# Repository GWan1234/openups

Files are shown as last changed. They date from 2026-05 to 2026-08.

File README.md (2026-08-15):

# OpenUPS-ESP32S3

基于 ESP32-S3 的智能锂电池 UPS 控制系统，使用 BQ24780S/BQ24800 充电管理芯片与 BQ76920 电池监控芯片实现BMS管理，支持 3-5 串锂离子/磷酸铁锂电池，12-19V 宽电压输入。

以下英文为机翻：

An intelligent lithium battery UPS control system based on ESP32-S3, using BQ24780S/BQ24800 charger IC and BQ76920 battery monitor IC for BMS management, supporting 3-5 cell Li-ion/LiFePO4 batteries with 12-19V wide voltage input.

> **为什么不用铅酸 UPS？** 铅酸 UPS 待机功耗 10W+，体积笨重。本项目面向小功率主机、NAS、软路由、网络设备等场景，锂电池方案更小巧、更省电、更安静。
> **Why not lead-acid UPS?** Lead-acid UPS has 10W+ standby power consumption and bulky size. This project targets low-power hosts, NAS, soft routers, and network devices — lithium battery solutions are smaller, more energy-efficient, and quieter.

> **会不会炸飞老铁？** 做这个东西的初衷就是思考——为什么锂电池不安全？一个是电池管理问题，一个是心理暗示。电池管理方面，放弃粗暴的浮充方式，可设定充电起止范围，让电池在最佳区间保存，同时可精准限定充电电压、电流，还可以限定充电窗口时间，再就是电池管理芯片也要用好的，很多芯片的误差范围很大。心理方面，那就把所有信息都透明显示、可监控，这不还可以用 HA 或者米家联动嘛。其实家里锂电池设备好多——笔记本电脑、各种吸尘器、扫地机器人、洗地机、牙刷、剃须刀……如果谈不安全，都不安全。而且本项目的设计就是让电池一直处于安全的中间电量阶段范围（40%～80%），UPS 充电次数很少，一年也就几次。
> **Will it explode?** The original motivation was to think — why are lithium batteries unsafe? Two factors: battery management and psychological perception. On management: we abandon crude float charging, allowing configurable charge start/stop ranges to keep batteries in optimal zones, with precise voltage/current limits and time windows. Quality battery management chips matter — many have large error margins. On perception: display all information transparently and make it monitorable — you can even integrate with Home Assistant or Xiaomi Home. Actually, many household devices use lithium batteries — laptops, vacuums, robot vacuums, floor washers, electric toothbrushes, razors... If we're talking about safety risks, they all have them. Moreover, this project keeps batteries in the safe middle range (40%~80%), with very few charge cycles per year — just a few times.

> **为什么不用磷酸铁锂？** 磷酸铁锂长期处于浅充浅放状态，库仑计会有巨大积累误差，也许某天真正停电就失速了。综合来说，还是三元锂更符合预期。
>
> **Why not LiFePO4?** LiFePO4 in long-term shallow charge/discharge cycles causes huge accumulated errors in the coulomb counter — when a real power outage occurs, it may fail unexpectedly. Overall, ternary lithium (NCM/NCA) better meets expectations.
>
> ----------------------------------------------------------
>
> **最新代码新增了磷酸铁锂的支持，可我没有磷酸铁锂电池，所以并没有测试，请自行评估。**
>
> **The latest commit adds support for LFP (LiFePO₄) batteries. However, since I don't have an LFP battery on hand, this feature has not been tested. Use at your own risk.**

> **怎么接入米家？** 把米家温湿度计上的传感器拆掉，通过 I2C 连接到主板。系统模拟 I2C Slave（SHTC3 协议），将电池温度和 SOC（用湿度字段替代）传送给米家温湿度计，从而接入米家智能家居生态。当然这个功能是可选的——毕竟要拆一只温湿度计来实现。详见 [版本说明 - v2 特性变化](#v2-特性变化)。
> **How to integrate with Xiaomi Home?** Remove the sensor from a Xiaomi temperature/humidity monitor and connect it to the mainboard via I2C. The system simulates an I2C Slave (SHTC3 protocol), transmitting battery temperature and SOC (using the humidity field) to the Xiaomi monitor, thereby integrating into the Xiaomi smart home ecosystem. This feature is optional — it requires disassembling a monitor. See [Version Notes - v2 Feature Changes](#v2-feature-changes).

> **电池的选择** 其实UPS常年都是空置，很难使用到一次，一年也就充电多次，没有必要用全新的电池，但一定要用可靠的电池。比如说家里各个设备淘汰下来的电池，吸尘器，扫地机器人，洗地机，甚至手电钻等等，都可以梯次利用，作为ups发光发热。不过这些设备电池在使用前，一定要尽量充电到电压一致，靠bq76920那微弱的平衡能力（增加外置大功率平衡是没有必要的），是需要很久很久很久的。
> **Battery selection** UPS units are typically idle, rarely used, and only charge a few times per year — there's no need for brand new batteries, but they must be reliable. For example, retired batteries from household devices (vacuums, robot vacuums, floor washers, even power drills) can be repurposed for UPS use. However, these batteries must be charged to matching voltages before use — relying on the BQ76920's slow balancing capability (external high-power balancing is unnecessary) would take an extremely long time.

## 功能特性
## Features

### 核心功能
### Core Features

- **USB HID UPS** — ESP32-S3 原生 USB 接口，Windows/macOS/Linux 自动识别为标准 UPS 设备，支持低电量安全关机
- **USB HID UPS** — ESP32-S3 native USB interface, automatically recognized as standard UPS device by Windows/macOS/Linux, supports low-battery safe shutdown
- **充放电管理** — BQ24780S/BQ24800 充电控制，支持自适应充电电流、定时充电窗口（5 组周计划）、混合供电模式
- **Charge/Discharge Management** — BQ24780S/BQ24800 charging control with adaptive charge current, scheduled charging windows (5 weekly plans), hybrid power supply mode
- **电池管理** — BQ76920 电池监控，库仑计 SOC 计算、SOH 学习、自动均衡、多重保护（OV/UV/OCD/SCD/OT）
- **Battery Management** — BQ76920 battery monitoring with coulomb counter SOC calculation, SOH learning, auto-balancing, multiple protections (OV/UV/OCD/SCD/OT)
- **Web 仪表盘** — SPA 单页应用，macOS 风格 UI，实时 WebSocket 数据推送（3 秒间隔）
- **Web Dashboard** — SPA single-page application with macOS-style UI, real-time WebSocket data push (3-second interval)
- **OTA 固件更新** — 网页拖拽上传固件，带签名校验，双分区安全升级
- **OTA Firmware Update** — Web-based drag-and-drop firmware upload with signature verification, dual-partition safe upgrade
- **MQTT 集成** — Home Assistant 自动发现，支持 TLS 加密连接
- **MQTT Integration** — Home Assistant auto-discovery with TLS encrypted connection support
- **Prometheus 监控** — `/metrics` 端点，可直接接入 Grafana
- **Prometheus Monitoring** — `/metrics` endpoint, directly compatible with Grafana
- **米家集成** — 借助米家温湿度计，绕道接入米家，实现温度，SOC与米家系统联动
- **Xiaomi Home Integration** — Via Xiaomi temperature/humidity monitor, indirect integration with Xiaomi Home for temperature and SOC linkage
- **WEBHOOK—**新增webhook用于信息推送（测试中，欢迎反馈）
- **WEBHOOK—**New webhook added for message pushing (in testing, feedback is welcome)

### 保护机制
### Protection Mechanisms

| 保护类型 | 说明 |
| Protection Type | Description |
|---|---|
| 过压保护 (OV) | 单体电压超阈值，切断充电 FET |
| Overvoltage Protection (OV) | Cell voltage exceeds threshold, charging FET cut off |
| 欠压保护 (UV) | 单体电压低于阈值，切断放电 FET |
| Undervoltage Protection (UV) | Cell voltage below threshold, discharging FET cut off |
| 过流保护 (OCD) | 放电电流超限 |
| Overcurrent Protection (OCD) | Discharge current exceeds limit |
| 短路保护 (SCD) | 短路快速响应 |
| Short Circuit Protection (SCD) | Fast short-circuit response |
| 过温保护 | 板载 + 环境温度双重检测 |
| Overtemperature Protection | Board + ambient temperature dual detection |
| 充电超时 | 防止异常长时间充电 |
| Charge Timeout | Prevents abnormal prolonged charging |
| 系统状态机 | INIT → NORMAL → WARNING → CRITICAL 四级状态管理 |
| System State Machine | INIT → NORMAL → WARNING → CRITICAL four-level state management |

## 版本说明
## Version Notes

### v1 与 v2 区别
### Differences between v1 and v2

v2 与 v1 最大的区别是从开发板换成了贴片模块，去掉了一个 USB 口，缩小了整体体积。
The biggest difference between v2 and v1 is switching from a development board to a SMT module, removing one USB port, and reducing overall size.

v1 与 v2 都支持 **BQ24780S** 与 **BQ24800**，两者引脚兼容。区别是 BQ24800 支持升压输出——有总比没有好。
Both v1 and v2 support **BQ24780S** and **BQ24800**, which are pin-compatible. The difference is BQ24800 supports boost output — better to have than not.

> v2 用 **4 层板**，6 层板是因为领错了券，纯属浪费，对不起嘉立创。
> v2 uses a **4-layer PCB**; the 6-layer board was due to a coupon mistake — a waste, apologies to JLCPCB.

### v2 特性变化
### v2 Feature Changes

v2 没有使用开发板，因此没有 GPIO48 的 RGB 灯。GPIO47/GPIO48 改为 **I2C Slave** 接口，并加了上拉电阻。设计想法是用 GPIO10 模拟电量信号给米家温湿度计供电来显示电量，温度与湿度（可以替换为比如主板温度）通过 I2C Slave 发送给米家温湿度计，从而接入米家智能家居生态。
v2 doesn't use a development board, so there's no GPIO48 RGB LED. GPIO47/GPIO48 are changed to **I2C Slave** interface with pull-up resistors. The design idea is to use GPIO10 to simulate battery level signal for the Xiaomi monitor to display SOC, while temperature and humidity (replacable with e.g. board temperature) are sent via I2C Slave to the Xiaomi monitor, integrating into the Xiaomi smart home ecosystem.

当然，你也可以不用这个功能。米家温湿度计拆下来的传感器没有用了，可以焊在板子预留的焊盘上（代码还没写，回头加上）。到时候是不是可以不用焊接 CN6 以及环境温度 NTC 电阻，用这个替代？
Of course, you can choose not to use this feature. The sensor removed from the Xiaomi monitor can be soldered to the reserved pads on the board (code not yet written, will be added later). Could this replace soldering CN6 and the ambient temperature NTC resistor?

CN6 位置也可以直接把插件 NTC 电阻焊上去，不用那个插座。
The CN6 position can also directly accept a through-hole NTC resistor soldered in place, without using the socket.

> v2 的外壳还没做，代码持续调试升级中，外壳后续做好了再更新。
> v2 enclosure not yet designed; code is continuously being debugged and updated; enclosure will be added later.

### 首次下载程序
### First-Time Programming

启动时按住 **BOOT** 按键（从上到下第二个按钮），再按第三个按钮 **REBOOT**，即可进入下载模式。之后都可以直接通过网页 OTA 更新。
Hold the **BOOT** button (second button from top) during startup, then press the third button **REBOOT** to enter download mode. After that, updates can be done directly via web OTA.

从上往下，v1版本的按键依次是：**电池的激活按键，网络与配置重置按键**

v2版本的按键依次是：**电池的激活按键，esp32s3的boot引导按键，esp32s3的reset按键，网络与配置的重置按键**

led灯从左往右依次为：**ACpower，充电，放电，wifi指示（红色表示未连接，绿色表示已连接wifi）**

### **焊接提示**
### Soldering Tips

焊接板子时，**LDO 5V→3.3V 先不要焊**，先确认 5V 供电正常后再焊上去，以免一波带走芯片。
When soldering the board, **do not solder the LDO 5V→3.3V first** — verify 5V power is normal before soldering it to avoid damaging the chip.

## 硬件
## Hardware

### 关键参数
### Key Specifications

| 参数 | 值 |
| Parameter | Value |
|---|---|
| 输入电压 | 12-19V DC |
| Input Voltage | 12-19V DC |
| 充电电流 | 最高 8128mA（BQ24780S/BQ24800） |
| Charge Current | Up to 8128mA (BQ24780S/BQ24800) |
| 放电电流 | 最高 20A |
| Discharge Current | Up to 20A |
| 输入电流 | 最高 8064mA |
| Input Current | Up to 8064mA |
| 电池类型 | 3-5 串 Li-ion / LiFePO4 |
| Battery Type | 3-5 cell Li-ion / LiFePO4 |
| 电流采样电阻 | 10mΩ（充电侧）/ 5mΩ（放电侧） |
| Current Sense Resistor | 10mΩ (charge side) / 5mΩ (discharge side) |
| I2C 总线 | GPIO11(SDA) / GPIO12(SCL)，100kHz |
| I2C Bus | GPIO11(SDA) / GPIO12(SCL), 100kHz |

### 输出特性说明
### Output Characteristics

这个 UPS 本质上是**电源直通输出**，不具备变压、稳压功能，但可以在电源输出不足的时候，由电池来一起混合输出。当电源掉电的时候，输出的电压实际上就是电池本身的电压，这一点要注意。当然，现在的光猫、路由器、小主机本质上也是宽电压设备，比如 12V 的设备，9-13V 也没什么问题。
This UPS is essentially a **pass-through power output** without voltage conversion or regulation, but it can hybrid-output with the battery when the power supply is insufficient. When power fails, the output voltage is actually the battery's own voltage — keep this in mind. Of course, modern ONTs, routers, and mini PCs are typically wide-voltage devices; for example, a 12V device works fine at 9-13V.

主控 BQ24780S 是可以直接换成 **BQ24800** 的，两者引脚兼容。BQ24800 支持设定一个目标电压，可以让电池升压输出，从而在电源掉电时维持稳定的输出电压。v1 与 v2 均支持 BQ24800（详见[版本说明](#版本说明)）。
The main charger BQ24780S can be directly replaced with **BQ24800** — they are pin-compatible. BQ24800 supports setting a target voltage, enabling boost output from the battery to maintain stable output voltage during power loss. Both v1 and v2 support BQ24800 (see [Version Notes](#version-notes)).

### ESP32 开发板（v1）
### ESP32 Development Board (v1)

v1 使用 **ESP32-S3 N16R8** 版本的开发板（16MB Flash / 8MB PSRAM）。插入时**注意核对引脚排列和插入方向**，反接可能损坏开发板或主板。
v1 uses the **ESP32-S3 N16R8** development board (16MB Flash / 8MB PSRAM). **Verify pin arrangement and insertion direction** — reverse insertion may damage the board or mainboard.

> v2 使用贴片模块，无需开发板，详见[版本说明](#版本说明)。
> v2 uses an SMT module, no development board needed. See [Version Notes](#version-notes).

### 电池夹选择
### Battery Holder Selection

电池组有条件的**尽量选择直接点焊成组**，接触电阻最小、最可靠。
If possible, **directly spot-weld battery packs** — this provides the lowest contact resistance and highest reliability.

如果使用电池夹，建议如下：
If using battery holders, recommendations如下:

| 类型 | 材质 | 优缺点 |
| Type | Material | Pros/Cons |
|---|---|---|
| 插针电池夹 | 钢片 | 夹持力强，但**过紧**，拆装困难 |
| Pin battery holder | Steel | Strong grip, but **too tight**, difficult to install/remove |
| 贴片电池夹 | 铜材质 | 导电好，但**过松**，接触不可靠 |
| SMT battery holder | Copper | Good conductivity, but **too loose**, unreliable contact |
| **贴片铜弹片 + 螺旋弹簧**（推荐） | 黄铜/紫铜 | 导电好，弹簧提供足够的回弹力，**推荐方案** |
| **SMT copper spring + coil spring** (Recommended) | Brass/Copper | Good conductivity, spring provides sufficient rebound force, **recommended solution** |

推荐方案：[贴片铜弹片](https://item.taobao.com/item.htm?id=833701074625) + 线径 0.8mm × 外径 5mm × 长度 50mm 的螺旋弹簧配合使用。弹片负责导电，弹簧负责提供夹持力。
Recommended: [SMT copper spring](https://item.taobao.com/item.htm?id=833701074625) + coil spring (wire diameter 0.8mm × outer diameter 5mm × length 50mm). The copper spring handles conductivity, the coil spring provides clamping force.

> **不建议使用钢片电池夹**，夹持力过大容易损伤电池外壳；纯铜弹片弹力不足，需要搭配螺旋弹簧。
> **Not recommended: steel battery holders** — excessive clamping force can damage battery casing; pure copper springs lack sufficient elasticity and need coil spring pairing.

### 硬件注意事项
### Hardware Notes

- **电池选择** — 电池最好选择品质一致的，并保证初始电压一致。BQ76920 内置的平衡速度极慢，每天大概 20mV 不到。如果是大容量电池，要考虑在线路上增加外部平衡电路，BQ76920 也是支持的
- **Battery Selection** — Choose batteries with consistent quality and matching initial voltages. The BQ76920's built-in balancing is extremely slow, about 20mV per day. For large-capacity batteries, consider adding external balancing circuits on the lines — BQ76920 supports this
- **R27、R66** — 正常情况下**不需要焊接**，这两个电阻用于选择 NTC 与隔离 I2C 芯片的供电源
- **R27, R66** — Normally **do not need soldering** — these resistors select the power source for NTC and isolated I2C chip
- **I2C 隔离芯片** — PCB 设计使用 ISO1640BDR，也可以更换为 ISO1540DR。虽然 ISO1640 标称支持热拔插而 ISO1540 不支持，但实测 ISO1540DR 同样可以正常工作
- **I2C Isolation Chip** — PCB designed for ISO1640BDR, can also use ISO1540DR. Although ISO1640 nominally supports hot-swap while ISO1540 doesn't, testing shows ISO1540DR works fine
- **SW_activate 按键** — 电池刚接入或 BQ76920 进入运输模式后，需要按下此按键一次激活芯片
- **SW_activate Button** — After battery connection or when BQ76920 enters ship mode, press this button once to activate the chip
- **SW_reset 按键** — 长按数秒进入 WiFi AP 模式（重置网络）；开机时持续按住则重新进入配置模式
- **SW_reset Button** — Hold for several seconds to enter WiFi AP mode (reset network); hold during startup to re-enter configuration mode
- **H6、H7 跳线** — 使用 3S 电池需短接 H6，4S 电池需短接 H7（取决于电池串数），**请务必仔细确认后再上电**
- **H6, H7 Jumpers** — Short H6 for 3S batteries, short H7 for 4S batteries (depends on cell count), **please verify carefully before powering on**
- **LDO 焊接顺序（v2）** — 焊接板子时，LDO 5V→3.3V **先不要焊**，先确认 5V 供电正常后再焊上去，以免损坏芯片
- **LDO Soldering Order (v2)** — When soldering, **do not solder LDO 5V→3.3V first** — verify 5V power is normal before soldering to avoid chip damage
- **v1 飞线** — 电池正极与下方的 R010 检流电阻之间需要额外焊接一根导线，用于扩充导电能力，背面的 PCB 走线负载能力不够
- **v1 Wire Jumper** — An additional wire must be soldered between the battery positive terminal and the R010 sense resistor below to supplement conductivity — the backside PCB trace capacity is insufficient
- PCB 设计文件位于 `hardware/` 目录（EasyEDA Pro 格式），v2 设计文件在 `hardware/v2/`
- PCB design files are in the `hardware/` directory (EasyEDA Pro format), v2 design files in `hardware/v2/`
- 3D 打印外壳基于贴片电路板设计，可直接打印使用（文件后续上传）
- 3D printed enclosure is designed for the SMT board, can be directly printed (files to be uploaded later)

### 引脚定义
### Pin Definitions

<details>
<summary>点击展开完整引脚表 / Click to expand full pin table</summary>

| 功能 | GPIO | 说明 |
| Function | GPIO | Description |
|---|---|---|
| **I2C** | | |
| I2C_SDA | 11 | I2C 数据线 / I2C data line |
| I2C_SCL | 12 | I2C 时钟线 / I2C clock line |
| **BQ24780S/BQ24800** | | |
| ACOK | 13 | 电源适配器接入检测 / Power adapter detection |
| PROCHOT# | 14 | 芯片报警状态 / Chip alert status |
| TB_STAT# | 15 | 混合供电状态 / Hybrid power status |
| IADP | 1 | 输入电流 ADC / Input current ADC |
| IDCHG | 2 | 放电电流 ADC / Discharge current ADC |
| PMON | 9 | 系统功率监控 ADC / System power monitor ADC |
| **BQ76920** | | |
| ALERT | 16 | 电池管理报警中断 / Battery management alert interrupt |
| I2C_VCC | 6 | I2C 隔离芯片供电控制 / I2C isolation chip power control |
| **电压/温度 / Voltage/Temperature** | | |
| INPUT_VOLTAGE | 4 | 输入电压（1:10 分压） / Input voltage (1:10 divider) |
| BATTERY_VOLTAGE | 5 | 电池电压（1:10 分压） / Battery voltage (1:10 divider) |
| BOARD_TEMP | 7 | 板载温度（NTC 10K） / Board temperature (NTC 10K) |
| ENV_TEMP | 8 | 环境温度（NTC 10K） / Environment temperature (NTC 10K) |
| TEMP_POWER | 21 | NTC 供电使能 / NTC power enable |
| **LED 指示 / LED Indicators** | | |
| POWER_LED | 42 | 电源指示灯 / Power indicator |
| CHARGING_LED | 41 | 充电指示灯 / Charging indicator |
| DISCHARGING_LED | 40 | 放电指示灯 / Discharging indicator |
| WIFI_FAIL_LED | 39 | WiFi 连接失败 / WiFi connection failed |
| WIFI_OK_LED | 38 | WiFi 连接成功 / WiFi connection OK |
| RGB_LED | 48 | WS2812B 可编程 RGB（仅 v1，v2 改为 I2C Slave） / WS2812B programmable RGB (v1 only, v2 changed to I2C Slave) |
| **控制 / Control** | | |
| BUZZER | 18 | 蜂鸣器 / Buzzer |
| RESET_BTN | 17 | 重置按键（长按 2.5s+ 恢复出厂） / Reset button (hold 2.5s+ for factory reset) |

</details>

## 快速开始
## Quick Start

### 环境准备
### Environment Setup

1. 安装 [Arduino IDE](https://www.arduino.cc/en/software)
1. Install [Arduino IDE](https://www.arduino.cc/en/software)
2. 安装 ESP32-S3 开发板支持包（Board Manager 搜索 `esp32`）
2. Install ESP32-S3 board support package (search `esp32` in Board Manager)
3. 安装所需库：
3. Install required libraries:

| 库名 | 用途 |
| Library | Purpose |
|---|---|
| ESPAsyncWebServer | 异步 Web 服务器 / Async web server |
| AsyncTCP | 异步 TCP / Async TCP |
| ArduinoJson | JSON 序列化 / JSON serialization |
| FastLED | WS2812B RGB LED |
| Preferences | NVS Flash 存储 / NVS Flash storage |
| esp_task_wdt | 看门狗定时器 / Watchdog timer |
| **AsyncMQTT_ESP32** | MQTT 客户端（作者 khoih-prog，**请务必安装此版本**） / MQTT client (by khoih-prog, **must install this version**) |

> **注意**：MQTT 库请安装 **AsyncMQTT_ESP32**（作者 khoih-prog），不要安装其他 MQTT 库，API 不兼容。
> **Note**: For MQTT, install **AsyncMQTT_ESP32** (by khoih-prog) — do not install other MQTT libraries, as the API is incompatible.

### 编译烧录
### Compile and Flash

1. 用 Arduino IDE 打开项目根目录的 `sketch_jan14a.ino`
1. Open `sketch_jan14a.ino` in the project root with Arduino IDE
2. 选择开发板：ESP32-S3 Dev Module，并按如下配置：
2. Select board: ESP32-S3 Dev Module, with the following configuration:

   | 选项 | 值 |
   | Option | Value |
   |---|---|
   | USB CDC On Boot | **Disabled** |
   | Flash Mode | **QIO 80MHz** |
   | Flash Size | **16MB** |
   | Partition Scheme | **Custom**（使用项目自带的 `partitions.csv`） / (using project's `partitions.csv`) |
   | PSRAM | **OPI PSRAM** |
   | USB Mode | **USB-OTG** |

3. 编译并烧录
3. Compile and flash

### OTA 更新
### OTA Update

系统运行后，访问 `http://<设备IP>/update`，拖拽固件文件即可在线升级。固件需包含签名校验头。
After the system is running, visit `http://<device-IP>/update` and drag-drop the firmware file for online upgrade. Firmware must include a signature verification header.

## 首次使用
## First Use

### 按键操作说明
### Button Operations

| 按键 | 操作 | 效果 |
| Button | Operation | Effect |
|---|---|---|
| **SW_activate** | 短按 / Short press | 激活 BQ76920（电池接入或退出运输模式后使用） / Activate BQ76920 (after battery connection or exiting ship mode) |
| **SW_reset** | 长按数秒（运行中） / Hold for seconds (during operation) | 重置网络配置，进入 WiFi AP 热点模式 / Reset network config, enter WiFi AP hotspot mode |
| **SW_reset** | 开机时持续按住 / Hold during startup | 重新进入初始配置模式（清除 NVS 配置） / Re-enter initial configuration mode (clears NVS config) |
| **BOOT + RESET**（v2） | 启动时按住 BOOT，再按 RESET / Hold BOOT then press RESET at startup | 进入下载模式（首次烧录使用，之后可直接 OTA） / Enter download mode (for first flash, then use OTA) |

### 1. 硬件准备
### 1. Hardware Preparation

1. 选择 **ESP32-S3 N16R8** 开发板，插入主板时注意引脚方向（v2 使用贴片模块，无需此步骤）
1. Select **ESP32-S3 N16R8** development board, verify pin direction when inserting (v2 uses SMT module, skip this step)
2. 根据电池串数短接对应跳线：
2. Short the corresponding jumpers based on cell count:
   - 3S 电池 → 短接 **H6** / 3S battery → short **H6**
   - 4S 电池 → 短接 **H7** / 4S battery → short **H7**
   - 5S 电池 → 无需短接 / 5S battery → no jumper needed
3. 连接电池，按下 **SW_activate** 按键一次激活 BQ76920
3. Connect battery, press **SW_activate** once to activate BQ76920
4. 连接电源适配器（12-19V）
4. Connect power adapter (12-19V)

> **3S 电池用户注意**：3S 电池满电电压为 12.6V，如果使用 12V 电源适配器，由于充电芯片需要一定的压差才能工作，电池将无法充满。建议使用 **13V 左右**的电源适配器。当然，充不满也无大碍——锂电池保持 40%-80% 电量区间反而更有利于延长电池寿命。
> **3S battery users note**: 3S full charge voltage is 12.6V. If using a 12V adapter, the charger IC requires a voltage differential to operate, so the battery won't fully charge. Use a **~13V** adapter. Not fully charging is actually fine — keeping lithium batteries at 40%-80% SOC extends battery life.

### 2. 网络配置
### 2. Network Configuration

刷机后首次启动（NVS 无配置时），系统自动进入配置模式：
On first boot after flashing (when NVS has no config), the system automatically enters configuration mode:

1. 搜索并连接 WiFi 热点 **`OpenUPS-esp32`**（密码：`12345678`）
1. Search and connect to WiFi hotspot **`OpenUPS-esp32`** (password: `12345678`)
2. 浏览器访问 `http://192.168.4.1` 进入配置向导
2. Visit `http://192.168.4.1` in browser to enter configuration wizard
3. 按向导依次配置：WiFi → 网络 → 电池参数 → 硬件 → MQTT（可选）
3. Follow the wizard: WiFi → Network → Battery parameters → Hardware → MQTT (optional)
4. 配置完成后系统自动重启，连接到你配置的 WiFi 网络
4. After configuration, system auto-restarts and connects to your configured WiFi network

> WiFi 热点密码可在代码中自行修改。如果需要重新进入配置模式，开机时**持续按住 SW_reset** 即可。
> WiFi hotspot password can be modified in code. To re-enter configuration mode, **hold SW_reset during startup**.

### 3. 电池保护参数配置
### 3. Battery Protection Parameters

**系统启动后，务必在配置页面正确设置电池保护参数，所有单位均为 mV 和 mA：**
**After system startup, you must correctly set battery protection parameters on the configuration page. All units are mV and mA:**

| 参数 | 说明 | 示例（3S NCM） |
| Parameter | Description | Example (3S NCM) |
|---|---|---|
| 电池串数 | 3 / 4 / 5 | 3 |
| Cell Count | 3 / 4 / 5 | 3 |
| 标称容量 | 电池标称容量 (mAh) | 2500 |
| Nominal Capacity | Battery nominal capacity (mAh) | 2500 |
| 过压阈值 (OV) | 单体过压保护 (mV) | 4250 |
| OV Threshold | Cell overvoltage protection (mV) | 4250 |
| 过压恢复 | 单体过压恢复 (mV) | 4150 |
| OV Recovery | Cell overvoltage recovery (mV) | 4150 |
| 欠压阈值 (UV) | 单体欠压保护 (mV) | 2800 |
| UV Threshold | Cell undervoltage protection (mV) | 2800 |
| 欠压恢复 | 单体欠压恢复 (mV) | 3000 |
| UV Recovery | Cell undervoltage recovery (mV) | 3000 |
| 最大充电电流 | 充电电流上限 (mA) | 2000 |
| Max Charge Current | Charge current limit (mA) | 2000 |
| 最大放电电流 | 放电电流上限 (mA) | 5000 |
| Max Discharge Current | Discharge current limit (mA) | 5000 |
| 短路保护阈值 | 短路电流阈值 (mA) | 10000 |
| SCD Threshold | Short circuit current threshold (mA) | 10000 |
| 过温阈值 | 过温保护温度 (°C) | 55 |
| OT Threshold | Overtemperature protection (°C) | 55 |

> **请务必根据你所使用的电池规格设置这些参数，错误的参数可能导致电池损坏或安全事故！**
> **You must set these parameters according to your battery specifications. Incorrect parameters may cause battery damage or safety incidents!**

## Web 界面
## Web Interface

系统运行后，浏览器访问设备 IP 即可查看仪表盘：
After the system is running, visit the device IP in a browser to view the dashboard:

- **状态总览** — SOC 进度条、电压/电流/温度、5 节电池电压（高亮最大/最小值）、均衡状态、充放电模式
- **Status Overview** — SOC progress bar, voltage/current/temperature, 5 cell voltages (max/min highlighted), balancing status, charge/discharge mode
- **BMS 状态** — 详细电池信息、电池电压统计、BQ76920 寄存器转储
- **BMS Status** — Detailed battery info, cell voltage statistics, BQ76920 register dump
- **电源状态** — 输入/输出功率、充电控制状态、BQ24780S/BQ24800 寄存器转储
- **Power Status** — Input/output power, charge control status, BQ24780S/BQ24800 register dump
- **系统配置** — WiFi、BMS 参数、充放电管理、定时充电窗口、硬件控制
- **System Config** — WiFi, BMS parameters, charge/discharge management, scheduled charging windows, hardware control
- **ADC 校准** — 各 ADC 通道独立校准系数
- **ADC Calibration** — Independent calibration coefficients for each ADC channel
- **固件升级** — OTA 在线更新
- **Firmware Update** — OTA online update

## API 接口
## API Endpoints

| 端点 | 方法 | 说明 |
| Endpoint | Method | Description |
|---|---|---|
| `/` | GET | Web 仪表盘 / Web dashboard |
| `/api/status` | GET | 系统状态 JSON / System status JSON |
| `/api/bms` | GET | BMS 数据 JSON / BMS data JSON |
| `/api/power` | GET | 电源数据 JSON / Power data JSON |
| `/metrics` | GET | Prometheus 文本格式指标 / Prometheus text format metrics |
| `/api/calibration` | GET/POST | ADC 校准读写 / ADC calibration read/write |
| `/save` | POST | 保存配置 / Save configuration |
| `/firmware` | POST | OTA 固件上传 / OTA firmware upload |
| `/bms/shipmode` | POST | 进入 BMS 运输模式 / Enter BMS ship mode |
| `/ws` | WebSocket | 实时数据推送（3s 间隔） / Real-time data push (3s interval) |

## 架构概览
## Architecture Overview

```
┌─────────────────────────────────────────────────────────┐
│                    SystemManagement                      │
│              (FSM: INIT → NORMAL → WARNING → CRITICAL)  │
├──────────┬──────────┬──────────┬──────────┬─────────────┤
│   BMS    │  Power   │ Hardware │ WebServer│  WiFiManager│
│ (BQ76920)│(BQ24780S/│Interface │ + OTA    │   STA/AP    │
│          │ BQ24800) │          │          │             │
├──────────┴──────────┴──────────┴──────────┴─────────────┤
│                     EventBus (Pub/Sub)                   │
├─────────────────────────────────────────────────────────┤
│              Global State (Blackboard)                   │
│         System_Global_State (all telemetry)              │
├─────────────────────────────────────────────────────────┤
│            Driver Layer (I2C + CRC)                      │
│      BQ24780S/BQ24800 Driver |  BQ76920 Driver           │
└─────────────────────────────────────────────────────────┘
```

**额外服务：**
**Additional Services:**
- **UPS HID Service** — USB HID 协议，主机识别为标准 UPS / USB HID protocol, host recognizes as standard UPS
- **MQTT Service** — Home Assistant 自动发现 + TLS 支持 / Home Assistant auto-discovery + TLS support
- **ConfigManager** — NVS Flash 持久化所有配置 / NVS Flash persistent configuration storage

## 分区布局
## Partition Layout

| 分区 | 类型 | 大小 | 说明 |
| Partition | Type | Size | Description |
|---|---|---|---|
| nvs | data | 20KB | 配置存储 / Config storage |
| otadata | data | 8KB | OTA 数据 / OTA data |
| app0 | app | 4.5MB | 固件槽 A / Firmware slot A |
| app1 | app | 4.5MB | 固件槽 B / Firmware slot B |
| coredump | data | 64KB | 崩溃转储 / Crash dump |
| spiffs | data | 6MB | 文件系统 / File system |

## 目录结构
## Directory Structure

```
├── sketch_jan14a.ino              # 主程序入口 / Main program entry
├── partitions.csv                 # 分区表 / Partition table
├── src/
│   ├── bq24780s.h/.cpp            # BQ24780S/BQ24800 充电芯片驱动 / BQ24780S/BQ24800 charger driver
│   ├── bq76920.h/.cpp             # BQ76920 电池监控驱动 / BQ76920 battery monitor driver
│   ├── i2c_interface.h/.cpp       # I2C 通信（含 CRC） / I2C communication (with CRC)
│   ├── pins_config.h              # 引脚定义 / Pin definitions
│   ├── data_structures.h          # 数据结构定义 / Data structure definitions
│   ├── hardware_interface.h/.cpp  # GPIO/ADC/LED/蜂鸣器/按键 / GPIO/ADC/LED/buzzer/button
│   ├── bms.h/.cpp                 # 电池管理系统 / Battery management system
│   ├── power_management.h/.cpp    # 充放电管理 / Charge/discharge management
│   ├── system_management.h/.cpp   # 系统状态机 / System state machine
│   ├── config_manager.h/.cpp      # NVS 配置管理 / NVS configuration management
│   ├── web_server.h/.cpp          # HTTP/WebSocket/Prometheus/OTA
│   ├── WiFiManager.h/.cpp         # WiFi 管理 / WiFi management
│   ├── event_bus.h                # 事件总线 / Event bus
│   ├── event_types.h              # 事件类型定义 / Event type definitions
│   ├── ups_hid_service.h/.cpp     # USB HID UPS 服务 / USB HID UPS service
│   ├── mqtt_service.h/.cpp        # MQTT + HA 自动发现 / MQTT + HA auto-discovery
│   ├── time_utils.h/.cpp          # NTP 时间管理 / NTP time management
│   ├── utils.h/.cpp               # 工具函数 / Utility functions
│   ├── debug.h/.cpp               # 调试日志输出 / Debug log output
│   ├── SHTC3_Simulator.h/.cpp     # SHTC3 温湿度传感器模拟（I2C Slave） / SHTC3 sensor simulation (I2C Slave)
│   ├── XiaomiSensorBridge.h/.cpp  # 米家温湿度计数据桥接 / Xiaomi sensor data bridge
│   └── templates/                 # Web UI 模板 / Web UI templates
│       ├── html_templates.h       # HTML 页面结构 / HTML page structure
│       ├── css_templates.h        # 样式表 / Stylesheet
│       ├── js_templates.h         # JavaScript 逻辑 / JavaScript logic
│       └── page_templates.h       # 页面模板片段 / Page template fragments
├── hardware/
│   ├── openups_hardware.epro2     # 硬件工程文件(v1) / Hardware project file (v1)
│   ├── openups_gerber.zip         # Gerber 生产文件 / Gerber production files
│   └── v2/                        # v2 版本硬件文件 / v2 hardware files
│       ├── openups_all.epro2      # v2 硬件工程文件 / v2 hardware project file
│       ├── openups_v2_原理图.pdf   # v2 原理图 / v2 schematic
│       ├── PCB_4层非开发板版本.pdf # v2 PCB 图 / v2 PCB layout
│       ├── Gerber_4层非开发板版本_openups.zip  # v2 Gerber 生产文件 / v2 Gerber production files
│       ├── BOM_4层非开发板版本_openups.xlsx    # v2 物料清单 / v2 Bill of Materials
│       └── readme.txt             # v2 版本说明 / v2 version notes
└── doc/                           # 芯片寄存器文档 / Chip register documentation
    ├── bq24780s.pdf               # BQ24780S 数据手册 / BQ24780S datasheet
    ├── bq24780s寄存器解释.md       # BQ24780S 寄存器说明 / BQ24780S register guide
    ├── bq24800.pdf                # BQ24800 数据手册 / BQ24800 datasheet
    ├── bq24800寄存器解释.md        # BQ24800 寄存器说明 / BQ24800 register guide
    ├── bq76920.pdf                # BQ76920 数据手册 / BQ76920 datasheet
    ├── bq76920寄存器解释.md        # BQ76920 寄存器说明 / BQ76920 register guide
    ├── Datasheet_SHTC3.pdf        # SHTC3 温湿度传感器数据手册 / SHTC3 datasheet
    ├── iso1540.pdf                # ISO1540 I2C 隔离芯片数据手册 / ISO1540 datasheet
    └── iso1640.pdf                # ISO1640 I2C 隔离芯片数据手册 / ISO1640 datasheet
```

## 已知限制
## Known Limitations

- 代码目前处于**测试版本**，部分功能尚未完善
- Code is currently in **beta**, some features are not yet complete
- **暂时只支持三元锂电池（NCM/NCA）**，磷酸铁锂电池（LiFePO4）需要自行修改 `src/bms.h` 中的电压阈值与 SOC-OCV 电量对应表
- **Currently only supports ternary lithium (NCM/NCA)** — LiFePO4 requires manual modification of voltage thresholds and SOC-OCV lookup table in `src/bms.h`
- 硬件设计基于 EasyEDA Pro，暂无 KiCad 版本
- Hardware design is based on EasyEDA Pro, no KiCad version yet
- SOC 计算在电池首次使用时需要一次完整充放电循环进行校准
- SOC calculation requires one full charge/discharge cycle for calibration on first use

## 安全提示
## Safety Notice

> **本项目涉及锂电池充放电管理，操作不当可能存在安全风险。请确保你：**
> **This project involves lithium battery charge/discharge management. Improper operation may pose safety risks. Please ensure you:**
> - 了解锂电池安全知识
> - Understand lithium battery safety
> - 能够正确设置电池保护参数（OV/UV/OCD/SCD）
> - Can correctly set battery protection parameters (OV/UV/OCD/SCD)
> - 有基本的电子电路调试能力
> - Have basic electronic circuit debugging skills
> - 能够承担实验风险
> - Can accept experimental risks
>
> 作者不对因使用本项目造成的任何损失负责。
> The author is not responsible for any damages caused by using this project.

## 参与贡献
## Contributing

欢迎提交 Issue 和 Pull Request！
Issues and Pull Requests are welcome!

AI 时代，人人都是高级程序员。无论是代码优化、Bug 修复、功能增强还是文档改进，都欢迎参与。
In the AI era, everyone is a senior programmer. Whether it's code optimization, bug fixes, feature enhancements, or documentation improvements — all contributions are welcome.

webpage

HomeAssistant

PCB_正面

PCB_背面

实物

实物1

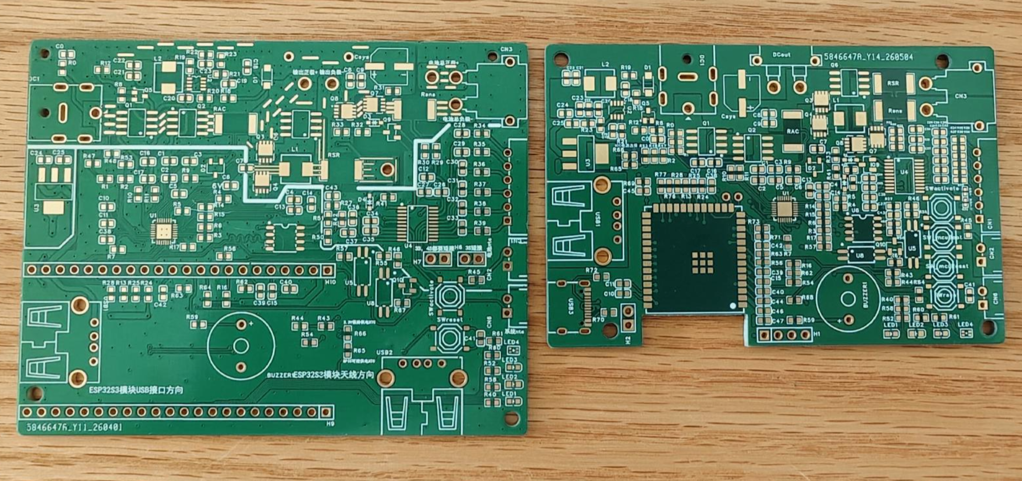
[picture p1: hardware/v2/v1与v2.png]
v1与v2


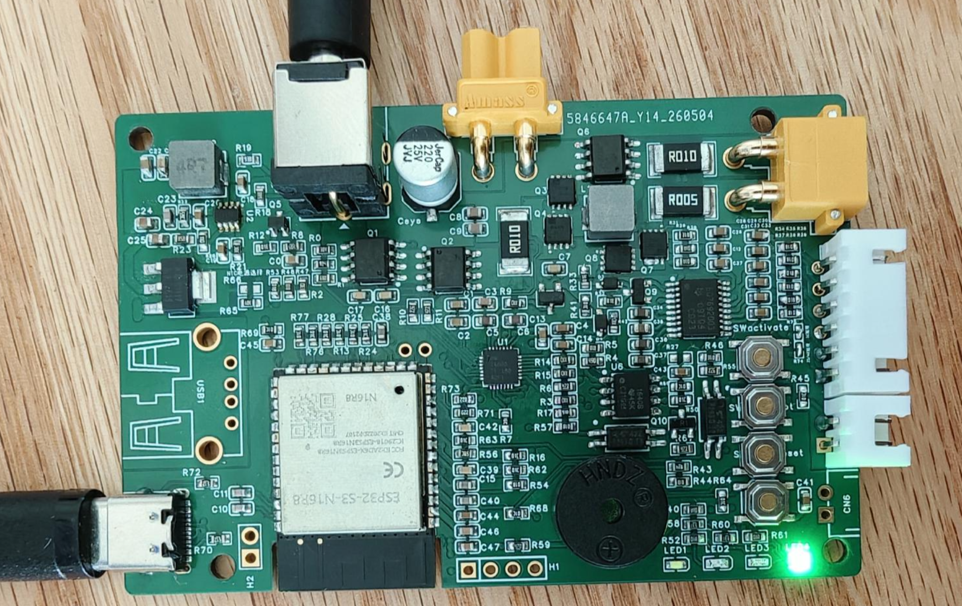
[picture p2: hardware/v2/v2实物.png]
v2实物


历史版本

## 致谢
## Acknowledgments

本项目从硬件设计到嵌入式软件开发，几乎全部由 AI 辅助完成。作者此前没有任何硬件开发和嵌入式编程经验，没有 AI 的帮助，这个项目不可能实现。
This project, from hardware design to embedded software development, was almost entirely assisted by AI. The author had no prior hardware development or embedded programming experience — without AI, this project would not have been possible.

特别感谢：
Special thanks to:

- **阿里巴巴通义千问（Qwen）**
- **Alibaba Qwen (Tongyi Qianwen)**
- **小米 MiMo 大模型**
- **Xiaomi MiMo LLM**

排名不分先后，都是伟大的公司！
In no particular order — all great companies!

感谢 **嘉立创 EDA** 和 **嘉立创集团**。没有这样免费的软件、免费的打板、方便的器件购买，是无法低成本完成这件事情的。整个过程除去时间成本（这是乐趣，不能算成本）外，其实也才几百元。无法想象。感谢中国的产业链！
Thanks to **EasyEDA** and **JLCPCB Group**. Without free software, free PCB fabrication, and convenient component purchasing, this could not have been done at low cost. Excluding time cost (which is fun and doesn't count), the total was only a few hundred RMB. Unbelievable. Thanks to China's manufacturing ecosystem!

AI 时代，人人都是高级程序员。
In the AI era, everyone is a senior programmer.

## 许可证
## License

本项目为开源项目，详见仓库许可信息。
This is an open source project. See repository license information for details.

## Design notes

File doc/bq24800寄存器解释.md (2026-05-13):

### Table 4. Battery Charger Command Summary

| 地址 | 寄存器名称 | 表号 | 读/写 | 描述 | 复位状态 (POR State) |
| :--- | :--- | :--- | :--- | :--- | :--- |
| 0x12H | ChargeOption0() | Table 5  | Read or Write | Charge Options Control 0 | 0xE108H |
| 0x3BH | ChargeOption1() | Table 6  | Read or Write | Charge Options Control 1 | **0xC220H** |
| 0x38H | ChargeOption2() | Table 7  | Read or Write | Charge Options Control 2 | **0x0384H** |
| 0x37H | ChargeOption3() | Table 8  | Read or Write | Charge Options Control 3 | 0x1A40H |
| 0x3CH | ProchotOption0() | Table 9  | Read or Write | PROCHOT Options Control 0 | 0x4A54H |
| 0x3DH | ProchotOption1() | Table 10 | Read or Write | PROCHOT Options Control 1 | 0x8120H |
| 0x3AH | ProchotStatus() | Table 11 | Read Only | PROCHOT status | 0x0000H |
| 0x14H | ChargeCurrent() | Table 12 | Read or Write | 7-bit Charge Current Setting | 0x0000H |
| 0x15H | ChargeVoltage() | Table 13 | Read or Write | 11-bit Charge Voltage Setting | 0x0000H |
| 0x39H | DischargeCurrent() | Table 15 | Read or Write | 6-bit Discharge Current Setting | 0x1800H, or 6144mA |
| **0x3EH** | **VsysMin** | Table 16 | **Read or Write** | **最小系统电压设置<br />7-bit Minimum System Voltage** | **0x2300, or 8960 mV** |
| 0x3FH | InputCurrent() | Table 14 | Read or Write | Setting6-bit Input Current Setting | 0x1000H, or 4096mA |
| 0xFEH | ManufacturerID() | - | Read Only | Manufacturer ID | 0x0040H |
| 0xFFH | DeviceID() | - | Read Only | Device ID | **0x38H** |

### 表5. ChargeOption0 寄存器 (0x12H)

| 位域 | 位名称 | 描述 |
| :--- | :--- | :--- |
| **[15]** | **Low Power Mode Enable**<br>(EN_LWPWR) | **0:** IC 仅在电池模式下以性能模式运行。PROCHOT、电流/功率监视器缓冲器和独立比较器遵循寄存器设置。<br>**1:** IC 仅在电池模式下以低功耗模式运行。当此位使能时，IC 处于最低静态电流。PROCHOT、放电电流监视器缓冲器、功率监视器缓冲器和独立比较器均被禁用。<br>**（复位后默认）** |
| **[14:13]** | **WATCHDOG 定时器调整**<br>(WDTMR_ADJ) | 设置连续 SMBus 写充电电压或充电电流命令之间的最大延迟。如果 IC 在看门狗时间段内未接收到对 REG0x14() 或 REG0x15() 的写操作，充电器转换器将停止以禁用充电和升压模式操作。过期后，定时器将在写入 REG0x14() 或 REG0x15() 时恢复。如果所有其他条件有效，充电或升压操作将恢复。<br>**00:** 禁用看门狗定时器<br>**01:** 启用，5 秒<br>**10:** 启用，88 秒<br>**11:** 启用看门狗定时器 (175 秒) **（复位后默认）** |
| **[12:10]** | **Reserved** | **0 - 保留** |
| **[9:8]** | **Switching Frequency**<br>(PWM_FREQ) | 转换器开关频率。<br>**00:** 600 kHz<br>**01:** 800 kHz **（复位后默认）**<br>**10:** 1 MHz<br>**11:** 保留 |
| **[7:6]** | **Reserved** | **0 - 保留** |
| **[5]** | **LEARN Mode Enable**<br>(EN_LEARN) | 电池 LEARN 模式使能。在 LEARN 模式下，ACFET 和 RBFET 关断，BATFET 导通。当 /BATPRES 为高电平时，IC 退出 LEARN 模式，此位被置回 0。当电池耗尽时，充电器无法使能 LEARN 模式。<br>**0:** 禁用 LEARN 模式 **（复位后默认）**<br>**1:** 使能 LEARN 模式 |
| **[4]** | **IADP Amplifier Gain for Primary Input**<br>(IADP_GAIN) | IADP 引脚电压与 ACP 和 ACN 之间电压的比值。<br>**0:** 20X **（复位后默认）**<br>**1:** 40X |
| **[3]** | **IDCHG Amplifier Gain**<br>(IDCHG_GAIN) | IDCHG 引脚电压与 SRN 和 SRP 之间电压的比值。<br>**0:** 8x，放电电流调节范围 0-32A。<br>**1:** 16x，放电电流调节范围 **（复位后默认）** |
| **[2:1]** | **Reserved** | **0 - 保留** |
| **[0]** | **Charge Inhibit**<br>(CHRG_INHIBIT) | 充电抑制。当此位为 0 时，如果 REG0x14() 和 REG0x15() 中有有效值，则使能电池充电。<br>**0:** 使能充电 **（复位后默认）**<br>**1:** 抑制充电 |

### 表6. ChargeOption1 寄存器 (0x3BH)

| 位域 | 位名称 | 描述 |
| :--- | :--- | :--- |
| **[15:14]** | **Battery Depletion Threshold**<br>(BAT_DEPL_VTH) | 电池欠压阈值。在 LEARN 周期中，当电池电压低于耗尽阈值时，IC 退出 LEARN 模式。在升压模式中，当电池电压低于耗尽阈值时，IC 退出升压模式。<br>**00:** 下降阈值 = 电压调节限制的 59.19% (~2.486V/电芯)<br>**01:** 下降阈值 = 电压调节限制的 62.65% (~2.631V/电芯)<br>**10:** 下降阈值 = 电压调节限制的 66.55% (~2.795V/电芯)<br>**11:** 下降阈值 = 电压调节限制的 70.97% (2.981V/电芯) **（复位后默认）** |
| **[13:12]** | **(RSNS_RATIO)** | 使用不同的输入采样电阻 RAC 和充电采样电阻 RSR 调整 PMON 计算。<br>**00:** RAC 和 RSR 1:1 **（复位后默认）**<br>**01:** RAC 和 RSR 2:1<br>**10:** RAC 和 RSR 1:2<br>**11:** 保留 |
| **[11]** | **EN_IDCHG** | IDCHG 引脚输出使能。<br>**0:** 禁用 IDCHG 输出以最小化静态电流 (Iq) **（复位后默认）**<br>**1:** 使能 IDCHG 输出 |
| **[10]** | **EN_PMON** | PMON 引脚输出使能。<br>**0:** 禁用 PMON 输出以最小化静态电流 (Iq) **（复位后默认）**<br>**1:** 使能 PMON 输出 |
| **[9]** | **PMON Gain**<br>(PMON_RATIO) | PMON 输出电流与总输入和电池功率的比率（使用 10 mΩ 采样电阻）。<br>**0:** 0.25 μA/W<br>**1:** 1 μA/W **（复位后默认）**<br>当采样电阻为 20/10 mΩ，或 10/20 mΩ，或 20/20 mΩ (RAC 和 RSR) 时：<br>**0:** 0.5 μA/W<br>**1:** 2 μA/W **（复位后默认）** |
| **[8]** | **Reserved** | **0 - 保留** |
| **[7]** | **Independent Comparator**<br>Reference (CMP_REF) | 独立比较器内部参考电压。<br>**0:** 2.3 V **（复位后默认）**<br>**1:** 1.2 V |
| **[6]** | **Independent Comparator**<br>Polarity (CMP_POL) | 独立比较器输出极性。<br>**0:** 当 CMPIN 高于内部阈值时，CMPOUT 为低电平 **（复位后默认）**<br>**1:** 当 CMPIN 高于内部阈值时，CMPOUT 为高电平 |
| **[5:4]** | **Independent Comparator**<br>Deglitch Time (CMP_DEG) | 独立比较器去抖时间，应用于 CMPOUT 变低的边沿。不适用于 CMPOUT 上升沿。<br>**00:** 禁用独立比较器<br>**01:** 使能独立比较器，输出去抖时间 1 μs <br>**10:** 使能独立比较器，输出去抖时间 2 ms**（复位后默认）**<br>**11:** 使能独立比较器，输出去抖时间 5 sec |
| **[3]** | **Power Path Latch-off Enable**<br>(EN_FET_LATCHOFF)  | 当独立比较器触发时，ACFET/RBFET 关断。锁定解除方式：上电复位 (POR) 或将此位写为 0。<br>**0:** 当独立比较器触发时，无电源路径锁定关闭 **（复位后默认）**<br>**1:** 当独立比较器触发时，电源路径锁定关闭。 |
| **[2]** | **Reserved** | **0 - 保留** |
| **[1]** | **Discharge SRN for Shipping Mode**<br>(EN_SHIP_DCHG) | 以最小 5-mA 电流为 SRN 引脚放电 140 ms。140 ms 后，此位被重置为 0。<br>**0:** 禁用放电模式 **（复位后默认）**<br>**1:** 使能放电模式 |
| **[0]** | **Reserved** | **0 - 保留** |

### 表7. ChargeOption2 寄存器 (0x38H)

| Bit | 名称 | 描述 |
| --- | --- | --- |
| 15：14 | <u>PKPWR_TOVLD (过载时间)</u> | 峰值功率模式的过载持续时间<br />00: 1 ms (default @ POR)<br/>01: 2 ms<br/>10: 5 ms<br/>11: 10 ms |
| 13 | <u>EN_PKPWR (峰值功率使能)</u>  | 0=禁用（POR）, 1=使能 (允许适配器短时过载) |
| 12-10  | Reserved | 保留 |
| 9-8 | <u>PKPWR_TMAX (周期时间)</u> | 峰值功率模式的周期总时间<br />00: 20 ms (default @ POR)<br/>01: 40 ms<br/>10: 80 ms<br/>11: 1 sec |
| 7 | EN_EXTILIM (外部 ILIM) | 外部 ILIM 引脚使能，用于设置充电和放电电流。 **0:** 充电/放电电流限制由 REG0x14() 和 REG0x39() 设置。 **1:** 充电/放电电流限制由 ILIM 引脚和寄存器设置的较低值决定。 **（复位后默认）** |
| 6 | <u>EN_BATT_BOOST (电池升压)</u> | 0=禁用（default @ POR）, 1=使能 (仅电池升压模式) |
| 5 | <u>VBOOST (升压电压)</u> | 0=VSYSMIN+1.5V default @ POR), 1=VSYSMIN+2.3V |
| 4-0 | Reserved | 保留 |

### 表8. ChargeOption3 寄存器 (0x37H)

| 位域 | 位名称 | 描述 |
| --- | --- | --- |
| **[15]**  | **Discharge Current Regulation Enable** (EN_IDCHG_REG) | 电池放电电流调节使能。 **0:** 禁用放电电流调节 **（复位后默认）** **1:** 使能放电电流调节 |
| **[14]**  | **Reserved** | **0 - 保留** |
| **[13]**  | <u>**ACDRV Disable (ACDRV_OFF)**</u> | Force ACFET/RBFET to turn off, even with good adapter present.<br/>0: ACFET/RBFET control based on "System Power Selection". (default at POR)<br/>1: Turn off ACFET/RBFET |
| **[12]**  | **ACOK Deglitch Time for Primary Input** (ACOK_DEG) | 调整 ACOK 上升沿去抖时间。 上电复位 (POR) 后，第一次插入适配器时，去抖时间始终为 150 ms，与寄存器位无关。从第二次插入适配器开始，去抖时间遵循位设置。当系统过流或系统短路导致 ACDET 被拉低至 2.4 V 以下时，1.3 秒去抖时间使 ACFET/RBFET 在下次开启前保持关闭足够长时间。 **0:** ACOK 上升沿去抖时间 150ms **1:** ACOK 上升沿去抖时间 1.3 sec **（复位后默认）** |
| **[11]**  | **Adapter Present Indicator** (ACOK_STAT) | 输入存在指示。逻辑与 ACOK 引脚相同。此位为只读。 **0:** AC 适配器不存在 **1:** AC 适配器存在 |
| **[10]**  | **ACOC Enable** (EN_ACOC) | 通过监测 ACP_ACN 电压进行 ACOC 保护。 **0:** 禁用 ACOC **（复位后默认）** **1:** 使能 ACOC |
| **[9]** | **ACOC Limit** (ACOC_VTH) | ACOC 保护阈值，通过监测 ACP_ACN 电压设置。 **0:** ICRIT 的 125% **1:** ICRIT 的 200% **（复位后默认）** |
| **[8]** | **Reserved** | **0 – 保留** |
| **[7]** | **HSFET VDS Threshold** (IFAULT_HI) | 通过监测高侧 MOSFET 漏源电压进行 MOSFET/电感短路保护。 **0:** 禁用 **（复位后默认）** **1:** 750 mV |
| **[6]** | **LSFET VDS Threshold** (IFAULT_LO) | 通过监测低侧 MOSFET 漏源电压进行 MOSFET/电感短路保护。也可作为升压功能期间的逐周期电流限制阈值。 **0:** 禁用 **1:** 250 mV **（复位后默认）** |
| **[5]** | **Fast DPM Threshold** (FDPM_VTH) | 快速 DPM 比较器阈值，用于进入混合电源升压模式。（升压模式的最小 DPM 设置：1536 mA） **0:** 107% (下降 93%) **（复位后默认）** **1:** 115% (下降 85%) |
| **[4:3]** | **Fast DPM Deglitch Time** (FDPM_DEG) | 从系统电流超过快速 DPM 阈值到电池放电进入升压模式的响应时间。 **00:** 响应时间 150 μs **（复位后默认）** **01:** 响应时间 250 μs **1X:** 响应时间 50 μs |
| **[2]** | **Hybrid Power Boost Mode Enable** (EN_BOOST) | 升压模式使能位。当 /BATPRES 从低电平变为高电平（电池移除）时，此位将被重置为零以禁用升压模式。 **0:** 禁用混合电源升压模式 **（复位后默认）** **1:** 使能混合电源升压模式 |
| **[1]** | **Boost Mode Indication** (BOOST_STAT) | 升压模式指示器。当设备处于升压模式时，此位变为低电平。此位为只读。 **0:** 充电器不在混合电源升压模式 **（复位后默认）** **1:** 充电器在混合电源升压模式 |
| **[0]** | **Reserved** | **0 – 保留** |

### 表9. ProchotOption0 寄存器 (0x3CH)

| 位域 | 位名称 | 描述 |
| --- | --- | --- |
| [15] | <u>**Reserved**</u> | **0 - 保留** |
| **[14:11]** | <u>**ICRIT Threshold** (ICRIT_VTH)</u> | ILIM2 threshold as percentage of DPM in REG0x3F(). At 250% setting, when IDPM is over 3.648A, clamp ILIM2 <br/>to 230% of IDPM.<br/>The current is measured on the RAC between ACP and ACN. ICRIT is set as 110% of ILIM2.<br/>0001 - 1001: 110% - 150%, step 5%<br/>1001: 150%, 1010: 160%, 1011: 170%, 1100: 180%, 1101: 200%, 1110: 220%; 1111: 250%<br/>Default 150% (1001) |
| **[10:9]**  | **ICRIT Deglitch time** (ICRIT_DEG) | 典型 ICRIT 去抖时间。 **00:** 10 μs **01:** 100 μs **（复位后默认）** **10:** 400 μs **11:** 800 μs |
| **[8]** | **Reserved** | **0 – 保留** |
| **[7:6]** | **VSYS Threshold** (VSYS_VTH) | 在 SRN 上测量，固定 20-μs 去抖时间。当 SRN 电压低于阈值时触发。 如果 REG0x15() 编程值低于 VSYS 阈值，建议不要在 PROCHOT 配置中使能 VSYS。 **00:** 5.75 V **01:** 6 V **（复位后默认）** **10:** 6.25 V **11:** 6.5 V |
| **[5]** | **PROCHOT Pulse Extension Enable** (EN_PROCHOT_EXT) | 当脉冲扩展使能时，保持 PROCHOT 引脚电压为低电平，直到主机写 0x3C[2] = 0。 **0:** 禁用脉冲扩展 **（复位后默认）** **1:** 使能脉冲扩展 |
| **[4:3]** | **PROCHOT Pulse Width** (PROCHOT_WIDTH) | 当 REG0x3C[5]=0 时的最小 PROCHOT 脉冲宽度。 **00:** 100 μs **01:** 1 ms **10:** 10 ms **（复位后默认）** **11:** 5 ms |
| **[2]** | **PROCHOT Pulse Clear** (PROCHOT_CLEAR) | 当 (0x3C[5] = 1) 时清除 PROCHOT 脉冲。 **0:** 清除 PROCHOT 脉冲并将 PROCHOT 引脚驱动为高电平 **1:** 空闲 **（复位后默认）** |
| **[1]** | **INOM Deglitch Time** (INOM_DEG) | 最大 INOM 去抖时间。INOM 阈值是 REG0x3F() 中 IDPM 的 110%。测量 ACP 和 ACN 之间的电流。当电流高于此阈值时触发。 **0:** 1 ms (必须是最大值) **（复位后默认）** **1:** 60 ms (最大值) |
| **[0]** | **Reserved** | **0 - 保留** |

### 表10. ProchotOption1 寄存器 (0x3DH)

| 位域 | 位名称 | 描述 |
| --- | --- | --- |
| **[15:10]** | **IDCHG Threshold** (IDCHG_VTH) | 6 位，范围 0 A 至 32256 mA，步进 512 mA。测量 SRN 和 SRP 之间的电流。当放电电流高于阈值时触发。 **默认:** 16384 mA (100000) |
| **[9:8]** | **IDCHG Deglitch Time** (IDCHG_DEG) | 典型 IDCHG 去抖时间。 **00:** 1.6 ms **01:** 100 μs **（复位后默认）** **10:** 6 ms **11:** 12 ms |
| **[7]** | **Reserved** | **0 - 保留** |
| **[6:0]** | **PROCHOT input current envelop selector** (PROFILE) | 当适配器存在时，PROCHOT 功能由以下位使能。 当适配器移除时，PROCHOT 配置中的 ICRIT、INOM、BATPRES 和 ACOK 功能自动禁用。比较器、IDCHG 和 VSYS 功能设置保留。当所有位为 0 时，PROCHOT 功能禁用。 **位 6:** 独立比较器, 0: 禁用 **（复位后默认）**; 1: 使能 **位 5:** ICRIT, 0: 禁用; 1: 使能 **（复位后默认）** **位 4:** INOM, 0: 禁用 **（复位后默认）**; 1: 使能 **位 3:** IDCHG, 0: 禁用 **（复位后默认）**; 1: 使能 **位 2:** VSYS, 0: 禁用 **（复位后默认）**; 1: 使能 **位 1:** BATPRES, 0: 禁用 **（复位后默认）**; 1: 使能 (单次上升沿触发) **位 0:** ACOK, 0: 禁用 **（复位后默认）**; 1: 使能 (单次下降沿触发) |

### 表11. ProchotStatus 寄存器 (0x3AH)

| 位域 | 位名称 | 描述 |
| --- | --- | --- |
| **[15:7]** | **Reserved** | **0 - 保留** |
| **[6:0]**  | **PROCHOT status** (Read only) | 在同一 PROCHOT 脉冲期间触发的所有事件的状态均设置为 1。寄存器在以下任一条件发生时重置： • 主机在 PROCHOT 变高后首次读取 • PROCHOT 变低以开始另一个脉冲。 **位 6:** 独立比较器, 0: 未触发; 1: 触发 **位 5:** ICRIT, 0: 未触发; 1: 触发 **位 4:** INOM, 0: 未触发; 1: 触发 **位 3:** IDCHG, 0: 未触发; 1: 触发 **位 2:** VSYS, 0: 未触发; 1: 触发 **位 1:** BATPRES, 0: 未触发; 1: 触发 **位 0:** ACOK, 0: 未触发; 1: 触发 |

### 表12. Charge Current 寄存器 (0x14H)，使用 10-mΩ 采样电阻

| 位域 | 位名称 | 描述 |
| --- | --- | --- |
| **0**  | Not used | 值忽略 |
| **1**  | Not used | 值忽略 |
| **2**  | Not used | 值忽略 |
| **3**  | Not used | 值忽略 |
| **4**  | Not used | 值忽略 |
| **5**  | Not used | 值忽略 |
| **6**  | **Charge Current, DACICHG 0** | 0 = 增加 0 mA 的充电器电流 1 = 增加 64 mA 的充电器电流 |
| **7**  | **Charge Current, DACICHG 1** | 0 = 增加 0 mA 的充电器电流 1 = 增加 128 mA 的充电器电流  |
| **8**  | **Charge Current, DACICHG 2** | 0 = 增加 0 mA 的充电器电流 1 = 增加 256 mA 的充电器电流  |
| **9**  | **Charge Current, DACICHG 3** | 0 = 增加 0 mA 的充电器电流 1 = 增加 512 mA 的充电器电流  |
| **10** | **Charge Current, DACICHG 4** | 0 = 增加 0 mA 的充电器电流 1 = 增加 1024 mA 的充电器电流 |
| **11** | **Charge Current, DACICHG 5** | 0 = 增加 0 mA 的充电器电流 1 = 增加 2048 mA 的充电器电流 |
| **12** | **Charge Current, DACICHG 6** | 0 = 增加 0 mA 的充电器电流 1 = 增加 4096 mA 的充电器电流 |
| **13** | Not used | 1 = 无效写入 |
| **14** | Not used | 1 = 无效写入 |
| **15** | Not used | 1 = 无效写入 |

### 表13. Charge Voltage 寄存器 (0x15H)

| 位域 | 位名称 | 描述 |
| --- | --- | --- |
| **0**  | Not used | 值忽略 |
| **1**  | Not used | 值忽略 |
| **2**  | Not used | 值忽略 |
| **3**  | Not used | 值忽略 |
| **4**  | **Charge voltage, DACV 0**  | 0 = 增加 0 mV 的充电器电压 1 = 增加 16 mV 的充电器电压 |
| **5**  | **Charge voltage, DACV 1**  | 0 = 增加 0 mV 的充电器电压 1 = 增加 32 mV 的充电器电压 |
| **6**  | **Charge voltage, DACV 2**  | 0 = 增加 0 mV 的充电器电压 1 = 增加 64 mV 的充电器电压 |
| **7**  | **Charge voltage, DACV 3**  | 0 = 增加 0 mV 的充电器电压 1 = 增加 128 mV 的充电器电压 |
| **8**  | **Charge voltage, DACV 4**  | 0 = 增加 0 mV 的充电器电压 1 = 增加 256 mV 的充电器电压 |
| **9**  | **Charge voltage, DACV 5**  | 0 = 增加 0 mV 的充电器电压 1 = 增加 512 mV 的充电器电压 |
| **10** | **Charge voltage, DACV 6**  | 0 = 增加 0 mV 的充电器电压 1 = 增加 1024 mV 的充电器电压  |
| **11** | **Charge voltage, DACV 7**  | 0 = 增加 0 mV 的充电器电压 1 = 增加 2048 mV 的充电器电压  |
| **12** | **Charge voltage, DACV 8**  | 0 = 增加 0 mV 的充电器电压 1 = 增加 4096 mV 的充电器电压  |
| **13** | **Charge voltage, DACV 9**  | 0 = 增加 0 mV 的充电器电压 1 = 增加 8192 mV 的充电器电压  |
| **14** | **Charge voltage, DACV 10** | 0 = 增加 0 mV 的充电器电压 1 = 增加 16384 mV 的充电器电压 |
| **15** | Not used | 1 = 无效写入 |

### 表14. Input Current 寄存器 (0x3FH)，使用 10-mΩ 采样电阻

| 位域 | 位名称 | 描述 |
| --- | --- | --- |
| **0**  | Not used | 值忽略 |
| **1**  | Not used | 值忽略 |
| **2**  | Not used | 值忽略 |
| **3**  | Not used | 值忽略 |
| **4**  | Not used | 值忽略 |
| **5**  | Not used | 值忽略 |
| **6**  | <u>Input current</u> | <u>64mA</u> |
| **7**  | **Input current, DACIIN 0** | 0 = 增加 0 mA 的输入电流 1 = 增加 128 mA 的输入电流  |
| **8**  | **Input current, DACIIN 1** | 0 = 增加 0 mA 的输入电流 1 = 增加 256 mA 的输入电流  |
| **9**  | **Input current, DACIIN 2** | 0 = 增加 0 mA 的输入电流 1 = 增加 512 mA 的输入电流  |
| **10** | **Input current, DACIIN 3** | 0 = 增加 0 mA 的输入电流 1 = 增加 1024 mA 的输入电流 |
| **11** | **Input current, DACIIN 4** | 0 = 增加 0 mA 的输入电流 1 = 增加 2048 mA 的输入电流 |
| **12** | **Input current, DACIIN 5** | 0 = 增加 0 mA 的输入电流 1 = 增加 4096 mA 的输入电流 |
| **13** | Not used | 1 = 无效写入 |
| **14** | Not used | 1 = 无效写入 |
| **15** | Not used | 1 = 无效写入 |

### 表15. Discharge Current 寄存器 (0x39H)，使用 10-mΩ 采样电阻

| 位域 | 位名称 | 描述 |
| --- | --- | --- |
| **0**  | Not used | 值忽略 |
| **1**  | Not used | 值忽略 |
| **2**  | Not used | 值忽略 |
| **3**  | Not used | 值忽略 |
| **4**  | Not used | 值忽略 |
| **5**  | Not used | 值忽略 |
| **6**  | Not used | 值忽略 |
| **7**  | Not used | 值忽略 |
| **8**  | Not used | 值忽略 |
| **9**  | **Discharge current, DACIIN 0** | 0 = 增加 0 mA 的放电电流 1 = 增加 512 mA 的放电电流 |
| **10** | **Discharge current, DACIIN 1** | 0 = 增加 0 mA 的放电电流 1 = 增加 1024 mA 的放电电流  |
| **11** | **Discharge current, DACIIN 2** | 0 = 增加 0 mA 的放电电流 1 = 增加 2048 mA 的放电电流  |
| **12** | **Discharge current, DACIIN 3** | 0 = 增加 0 mA 的放电电流 1 = 增加 4096 mA 的放电电流  |
| **13** | **Discharge current, DACIIN 4** | 0 = 增加 0 mA 的放电电流 1 = 增加 8192 mA 的放电电流  |
| **14** | **Discharge current, DACIIN 5** | 0 = 增加 0 mA 的放电电流 1 = 增加 16384 mA 的放电电流 |
| **15** | Not used | 1 = 无效写入 |

### <u>Table 6-16. Minimum System Voltage Register(0x3E)</u>

| BIT  | BIT NAME | DESCRIPTION |
| ---- | --- | --- |
| 15 | | Not used; 1 = invalid write |
| 14 | | Not used; 1 = invalid write |
| 13 | Minimum system voltage,DACVS5  | 0= Adds 0 mV of charger voltage 1 = Adds 8192mV of charger voltage |
| 12 | Minimum system voltage,DACVS4  | 0= Adds 0 mV of charger voltage 1= Adds 4096 mV of charger voltage |
| 11 | Minimum system voltage, DACVS3 | 0= Adds 0 mV of charger voltage 1= Adds 2048 mV of charger voltage |
| 10 | Minimum system voltage,DACVS2  | 0= Adds 0 mV of charger voltage 1= Adds 1024 mV of charger voltage |
| 9 | Minimum system voltage, DACVS1 | 0= Adds 0 mV of charger voltage 1= Adds 512mV of charger voltage |
| 8 | Minimum system voltage,DACVSO  | 0= Adds 0 mV of charger voltage 1= Adds 256 mV of charger voltage |
| 7 | | Not used; value ignored |
| 6 | | Not used; value ignored |
| 5 | | Not used; value ignored |
| 4 | | Not used; value ignored |
| 3 | | Not used; value ignored |
| 2 | | Not used; value ignored |
| 1 | | Not used; value ignored |
| 0 | | Not used; value ignored |

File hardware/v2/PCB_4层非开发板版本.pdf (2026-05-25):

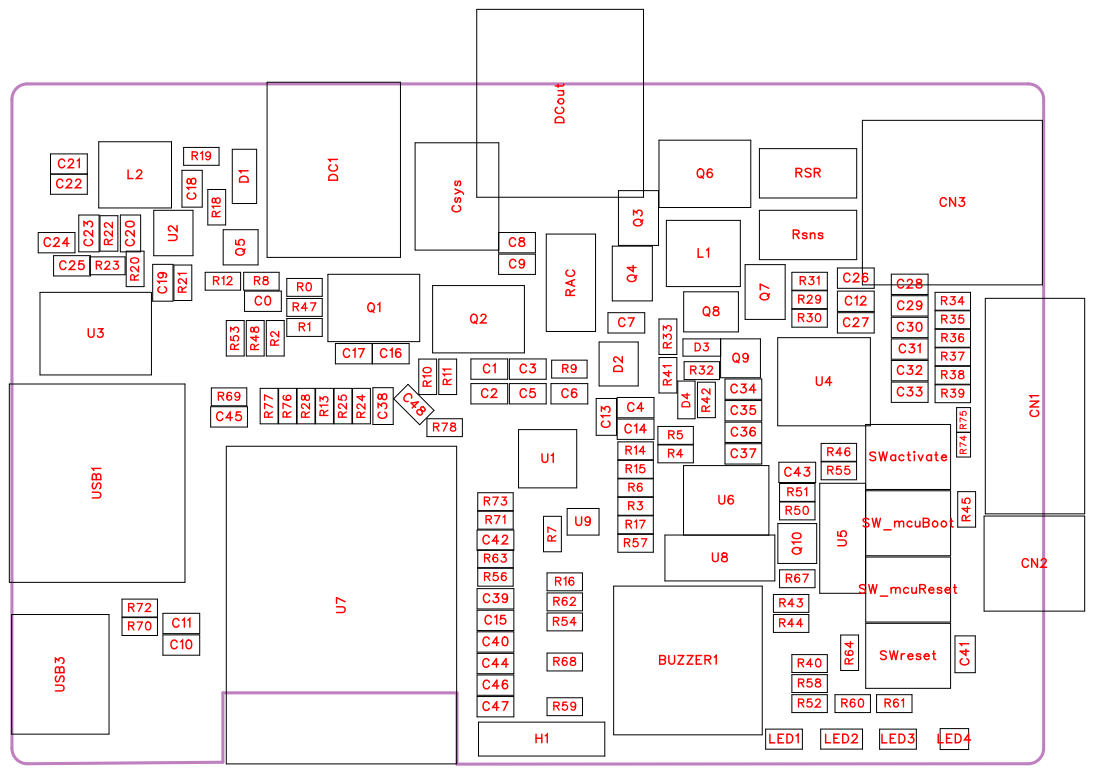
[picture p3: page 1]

U1 | C14 | R5 | C36 | SWactivate

R63 R56 | R16 | R67 | SW_mcuReset

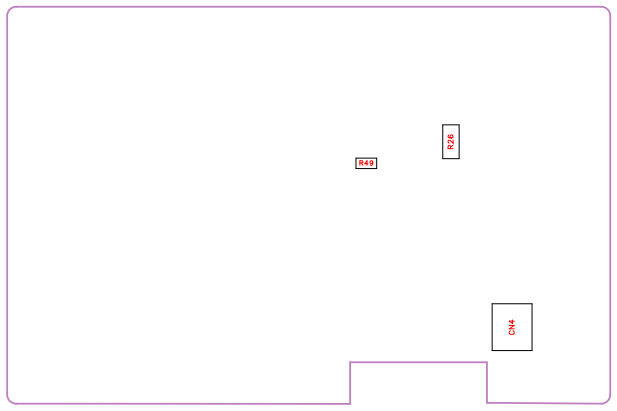
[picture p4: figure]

Quantity | Designator | Footprint | Value | Comment | Device
1 | BUZZER1 | BUZ-TH_BD 12.0-P7.60-D 0.6-FD | 2.3kHz | 2.3kHz | TMB12A03
1 | C0 | C0603 | 2.2uF | 2.2uF | CL10A225KA 8NNNC
23 | C1,C2,C3,C4,C12,C13,C14, C18,C19,C20,C26,C27,C28 ,C29,C30,C31,C32,C33,C4 1,C44,C45,C47,C48 | C0603 | 100nF | 100nF | CGA0603X7 R104K500JT ,FCC0603B1 04K500CT
5 | C5,C6,C34,C36,C37 | C0603 | 1uF | 1uF | CGA0603X5 R105K500JT
2 | C7,C16 | C0603 | 47nF | 47nF | CL10B473KB 8NNNC
5 | C8,C9,C24,C25,C46 | C0603 | 10uF | 10uF | CGA0603X5 R106K100JT ,CL10A106M A8NRNC
5 | C10,C11,C15,C38,C40 | C0603 | 100pF | 100pF | CL10C101JB 8NNNC
1 | C17 | C0603 | 1nF | 1nF | CL10B102KB 8NNNC
2 | C21,C22 | C0603 | 22uF | 22uF | CL10A226M P8NUNE
1 | C23 | C0603 | 33pF | 33pF | CL10C330JB 8NNNC
1 | C35 | C0603 | 4.7uF | 4.7uF | CGA0603X5 R475K250JT
3 | C39,C42,C43 | C0603 | 10nF | 10nF | CL10B103KB 8NNNC
1 | CN1 | CONN-TH_6 P-P2.50_HC ZZ0139-6 | | HX-XH2.54-6 PWZ | HX-XH2.54-6 PWZ
1 | CN2 | CONN-TH_H X-XH2.54-2P WZ | | HX-XH2.54-2 PWZ | HX-XH2.54-2 PWZ
1 | CN3 | CONN-TH_X T30PW-M | | XT30PW-M3 0.G.Y | XT30PW-M3 0.G.Y
1 | CN4 | CONN-SMD_ 4P-P1.00_W AFER-SH1.0 -4PWB | | WAFER-SH1 .0-4PWB | WAFER-SH1 .0-4PWB
1 | Csys | CAP-SMD_B D6.3-L6.6-W 6.6-LS7.3-FD -H7.7 | 220uF | 220uF | JVJ25V220M 6x8
1 | D1 | SOD-123FL_ L2.7-W1.8-L S3.8-RD | | SMF24A | SMF24A_C1 9077514

1 | D2 | SOT-23-3_L2 .9-W1.6-P1.9 0-LS2.8-BR | | BAT54C,215 | BAT54C,215
2 | D3,D4 | SOD-323_L1 .7-W1.3-LS2. 6-RD-1 | | BAT54WS | BAT54WS_C 7502694
1 | DC1 | DC-IN-TH_H C-DC-007B-2 .5 | | HC-DC-007B -2.5 | HC-DC-007B -2.5
1 | DCout | CONN-TH_X T30PW-F-1 | | XT30PW-F20 .G.Y | XT30PW-F20 .G.Y
1 | H1 | HDR-TH_4P-P2.54-V-M | | PZ254V-11-0 4P | PZ254V-11-0 4P
1 | L1 | IND-SMD_L5 .4-W5.2_FXL 05XX | 3.3uH | 3.3uH | FXL0530-3R 3-M
1 | L2 | IND-SMD_L5 .4-W5.2_FXL 0530 | 4.7uH | 4.7uH | FXL0530-4R 7-M
1 | LED1 | LED0603-RD | | GL0603UG0 1 | GL0603UG0 1
1 | LED2 | LED0603-FD | | GL0603UR0 1 | GL0603UR0 1
1 | LED3 | LED0603-RD _BLUE | | GL0603UB01 | GL0603UB01
1 | LED4 | LED-SMD_4 P-L1.6-W0.8-RD_1 | | XL-1608SUR UGC | XL-1608SUR UGC
3 | Q1,Q2,Q6 | SOP-8_L5.0-W4.0-P1.27-LS6.0-BL | | FDS6680A | FDS6680A
4 | Q3,Q4,Q7,Q8 | PDFN-8_L3. 1-W3.1-P0.6 5-LS3.4-BL | | SIS412DN-T 1-GE3-ES | SIS412DN-T 1-GE3-ES
1 | Q5 | SC-70-3_L2. 0-W1.3-P0.6 5-LS2.1-BL | | BSS138W | BSS138W_C 890266
1 | Q9 | SOT-23-3_L2 .9-W1.3-P1.9 0-LS2.4-BR- 1 | | BSS84 | BSS84_C742 0340
1 | Q10 | SOT-23-3_L2 .9-W1.3-P1.9 0-LS2.4-BR | | AO3401 | AO3401_C52 24195
1 | R0 | R0603 | 2 | 2 | 0603WAF20 0KT5E
2 | R1,R18 | R0603 | 499k | 499k | 0603WAF49 93T5E
1 | R2 | R0603 | 133k | 133k | 0603WAF13 33T5E

6 | R3,R9,R14,R15,R20,R42 | R0603 | 10 | 10 | 0603WAF10 0JT5E
1 | R4 | R0603 | 316k | 316k | 0603WAF31 63T5E
3 | R5,R44,R48 | R0603 | 100k | 100k | 0603WAF10 03T5E
5 | R6,R10,R11,R55,R67 | R0603 | 4.7k | 4.7k | 0603WAF47 01T5E
1 | R7 | R0603 | 14.3k | 14.3k | FRC0603F14 32TS
1 | R8 | R0603 | 3M | 3M | 0603WAF30 04T5E
5 | R12,R31,R32,R33,R46 | R0603 | 1M | 1M | 0603WAF10 04T5E
16 | R13,R16,R24,R25,R28,R41 ,R45,R50,R51,R62,R63,R6 4,R68,R69,R76,R77 | R0603 | 10k | 10k | FRC0603F10 02TS
1 | R17 | R0603 | 866k | 866k | FRC0603F86 63TS
1 | R19 | R0603 | 9.09k | 9.09k | FRC0603F90 91TS
1 | R21 | R0603 | 20k | 20k | 0603WAF20 02T5E
2 | R22,R56 | R0603 | 40.2k | 40.2k | FRC0603F40 22TS
1 | R23 | R0603 | 7.5k | 7.5k | 0603WAF75 01T5E
1 | R26 | R1206 | 0 | 0 | RE1206F1R0 00
6 | R29,R30,R40,R52,R61,R78 | R0603 | 100 | 100 | 0603WAF10 00T5E,FRC0 603F1000TS
9 | R34,R35,R36,R37,R38,R39 ,R53,R54,R57 | R0603 | 1k | 1k | 0603WAF10 01T5E
2 | R43,R47 | R0603 | 910k | 910k | FRC0603F91 03TS
1 | R49 | R0603 | | HNTC0603-1 03F3450FA | HNTC0603-1 03F3450FA
2 | R58,R60 | R0603 | 330 | 330 | 0603WAF33 00T5E
1 | R59 | R0603 | 47 | 47 | 0603WAF47 0JT5E
2 | R70,R72 | R0603 | 5.1k | 5.1k | FRC0603F51 01TS
2 | R71,R73 | R0603 | 22 | 22 | FRC0603F22 R0TS
2 | R74,R75 | R0402 | 0 | 0 | FRC0402F00 00TS

2 | RAC,RSR | R2512 | 10m | 10m | RE2512F3R0 10
1 | Rsns | R2512 | 5m | 5m | JER2512F3R 005
4 | SWactivate,SWreset,SW_m cuBoot,SW_mcuReset | SW-SMD_4P -L5.1-W5.1-P 3.70-LS6.5-T L_H1.5 | | TS-1187A-B-A-B | TS-1187A-B-A-B
1 | U1 | WQFN-28_L 4.0-W4.0-P0. 40-BL-EP | | BQ24780SR UYR | BQ24780SR UYR
1 | U2 | TSOT-23-8_ L2.9-W1.6-P 0.65-LS2.8-B L | | MP2315SGJ-Z | MP2315SGJ-Z
1 | U3 | SOT-223-3_L 6.5-W3.4-P2. 30-LS7.0-BR | | AMS1117-3. 3 | AMS1117-3. 3_C6186
1 | U4 | TSSOP-20_L 6.5-W4.4-P0. 65-LS6.4-BL | | BQ7692003P WR | BQ7692003P WR
2 | U5,U8 | SOP-4_L4.4-W2.8-P1.27-LS7.0-BR | | TLP293(GB-TPL,E | TLP293(GB-TPL,E
1 | U6 | SOIC-8_L4.9 -W3.9-P1.27-LS6.0-TL | | ISO1640BDR | ISO1640BDR
1 | U7 | WIRELM-SM D_ESP32-S3 -WROOM-1 | | ESP32-S3-W ROOM-1-N1 6R8 | ESP32-S3-W ROOM-1-N1 6R8
1 | U9 | DFN-4_L2.0-W2.0-P1.00-BL-EP | | SHTC3-TR-1 0KS | SHTC3-TR-1 0KS
1 | USB1 | USB-A-TH_A F-WJDG | | AF 90° WJDG | AF 90° WJDG
1 | USB3 | USB-C-SMD _TYPE-C-6PI N-2MD-073 | | TYPE-C 16PIN 2MD(073) | TYPE-C 16PIN 2MD(073)

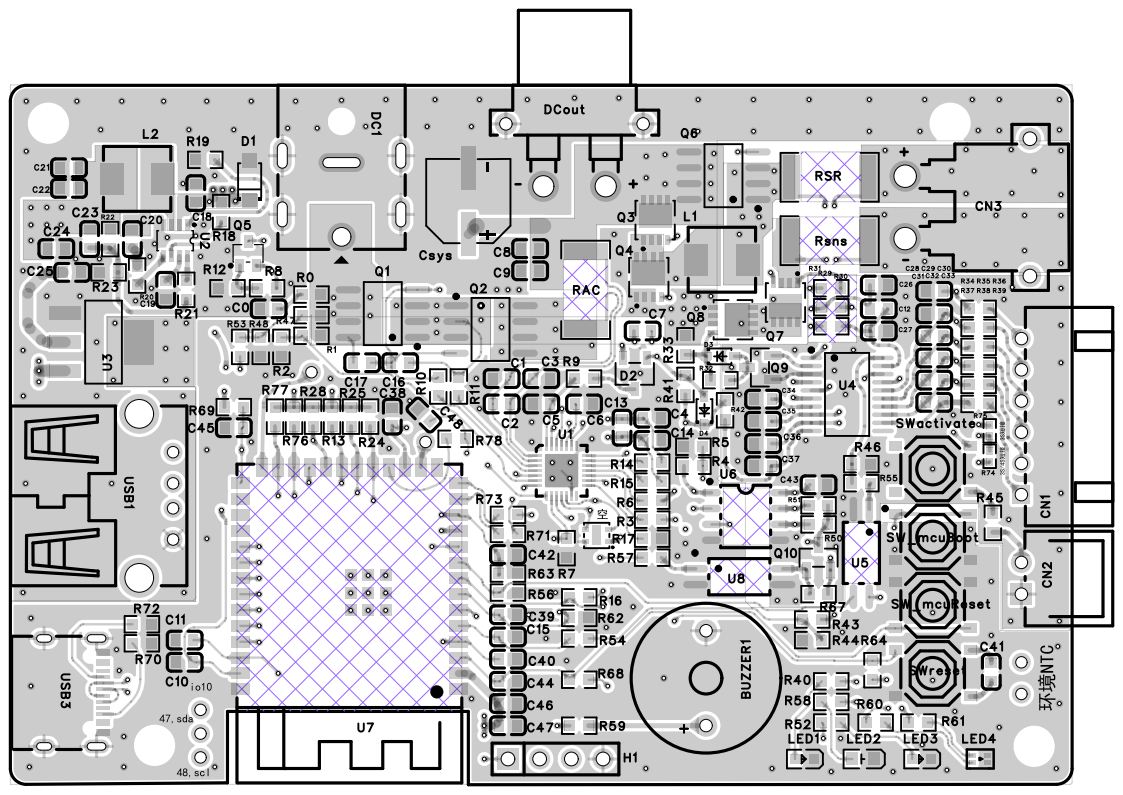
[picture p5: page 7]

Q3 L1 | RSR | +

RAC | R31 R29 R30

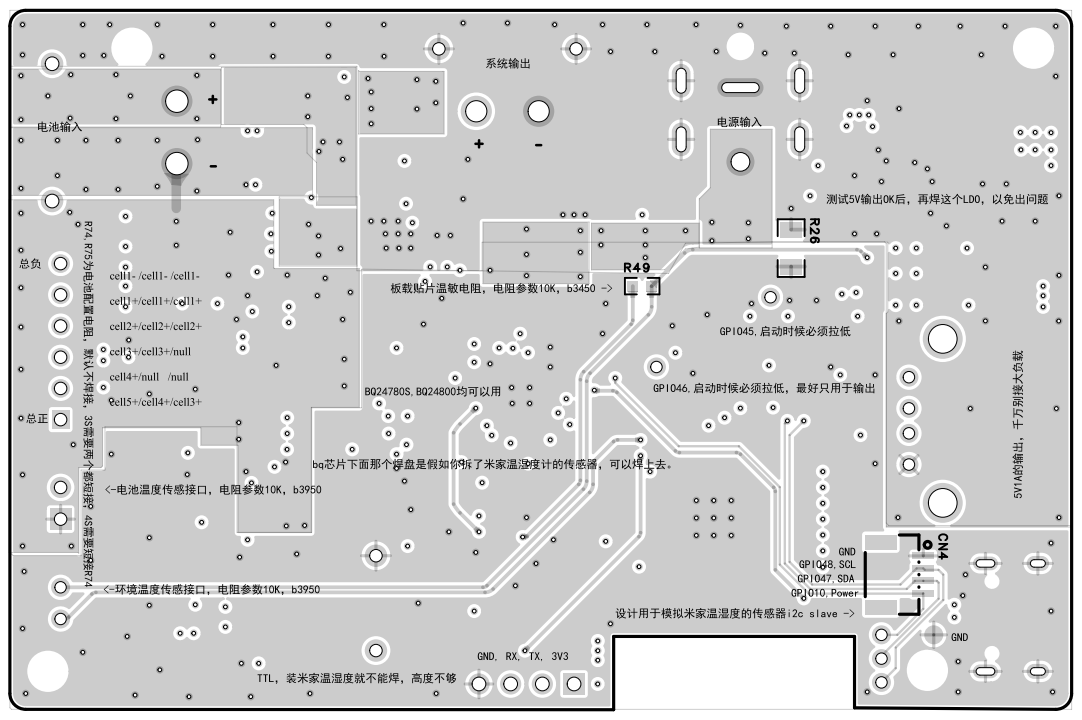
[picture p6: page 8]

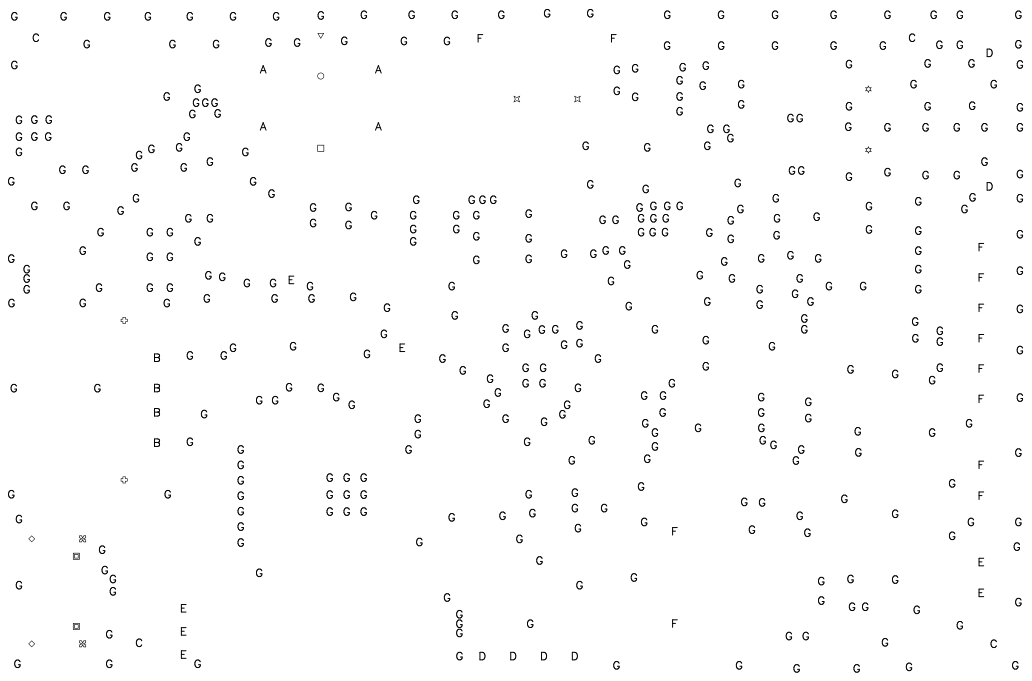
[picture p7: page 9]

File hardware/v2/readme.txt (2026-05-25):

v2与v1最大的区别就是从开发板换成了贴片模块。去掉了一个usb五福，缩小了体积。
v1与v2都支持bq24780s与bq24800。这俩的区别是24800支持升压输出，算是还可以，反正有总比没有好。
v2没有用开发板，就没有那个gpio48的rgb灯，把gpio47 gpio48换成了i2c的slave，也加了上拉。温度与湿度（替换为比如说主板温度）通过这个i2c slave发给米家温湿度计，从而接入米家。
当然，你也可以不用。米家温湿度计吹下来的传感器没有用了，可以焊在板子上面预留那个焊盘，代码还没写，回头加上，到时候是不是可以不用焊接CN6以及环境温度ntc电阻用这个替代？
cn6位置，想想也可以直接把插件ntc电阻焊上去，不要那个插座。

下载程序第一次：启动的时候按住boot，就是从上到下第二个按钮，然后按第三个按钮reboot，就进入到了下载模式。
以后都可以直接网页ota。

焊接板子的时候，ldo 5->3.3v那个先不要焊，先确认5v都ok了再最后焊上去，以免一波带走。

v2的外壳还没做，代码持续调试升级中，外壳后续做好了再更新。
//外壳已经做好了，后盖有两种，一个是没有pcb板，直接电池夹放上去的，另一个是有pcb板的。仔细看看就能看出来。电池有条件的永远还是推荐直接点焊成组，不用电池夹，电池夹是属于没有这个条件的次选。

v2用4层板的那个，6层板纯属浪费（6层板也不再更新了，没有实际意义），是因为领错了券，对不起嘉立创。

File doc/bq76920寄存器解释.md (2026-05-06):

### 1. 系统状态与控制寄存器 (System Status & Control)

这些寄存器用于监控芯片状态、清除故障以及控制 MOS 管和 ADC 的开关。

| 寄存器名称  | 地址 | 位 (Bit) | 名称 | 读/写 | 复位值 | 功能详解 |
| --- | ---- | --- | --- | ----- | --- | --- |
| SYS_STAT | 0x00 | 7 | CC_READY | RW | 0 | 库仑计数器就绪。1=新的电流积分数据已准备好；0=无新数据。需写1清除。 |
| | | 6 | RSVD | - | 0 | 保留，勿用。 |
| | | 5 | DEVICE_XREADY | RW | 0 | 内部芯片故障。1=检测到内部逻辑错误（通常由瞬态干扰引起）。需写1清除。 |
| | | 4 | OVRD_ALERT | RW | 0 | ALERT 引脚外部强制。1=ALERT 引脚被外部电路拉高（如二级保护IC）。需写1清除。 |
| | | 3 | UV | RW | 0 | 欠压故障。1=检测到电池欠压。需写1清除。清除后需重新开启 DSG。 |
| | | 2 | OV | RW | 0 | 过压故障。1=检测到电池过压。需写1清除。清除后需重新开启 CHG。 |
| | | 1 | SCD | RW | 0 | 放电短路故障。1=检测到短路。需写1清除。清除后需重新开启 DSG。 |
| | | 0 | OCD | RW | 0 | 放电过流故障。1=检测到过流。需写1清除。清除后需重新开启 DSG。 |
| CELLBAL1 | 0x01 | 7-5 | RSVD | R | 0 | 保留。 |
| (均衡控制1) | | 4-0 | CB5-CB1 | RW | 0 | 电芯均衡开关。1=开启对应电芯 (Cell 1~5) 的均衡；0=关闭。 |
| SYS_CTRL1 | 0x04 | 7 | LOAD_PRESENT  | R | 0 | 负载存在检测。仅当 CHG_OFF 时有效。1=CHG 引脚被外部拉高，说明负载仍连接在 PACK- 上。 |
| (系统控制1) | | 6-5 | RSVD | R | 0 | 保留。 |
| | | 4 | ADC_EN | RW | 0 | ADC 使能。1=开启电压/温度测量（同时开启 OV/UV 保护）；0=关闭以省电。 |
| | | 3 | TEMP_SEL | RW | 0 | 温度源选择。0=读取内部芯片温度；1=读取外部热敏电阻 (TSx) 温度。 |
| | | 2 | RSVD | RW | 0 | 保留，必须写 0。 |
| | | 1-0 | SHUT_A/B | RW | 0 | 关机序列控制。进入 SHIP 模式需按特定顺序写入： 1. 写 `0x01` (A=0, B=1) 2. 写 `0x02` (A=1, B=0)。 |
| SYS_CTRL2 | 0x05 | 7 | DELAY_DIS | RW | 0 | 禁用保护延时。1= bypass OV/UV/OCD/SCD 的延时逻辑（用于产线快速测试），故障立即触发。正常使用时应为 0。 |
| (系统控制2) | | 6 | CC_EN | RW | 0 | 库仑计数器常开。1=持续进行电流积分；0=关闭常开模式。 |
| | | 5 | CC_ONESHOT | RW | 0 | 单次电流测量。1=触发一次 250ms 的电流测量，完成后自动清零。仅在 CC_EN=0 时有效。 |
| | | 4-2 | RSVD | RW | 0 | 保留，必须写 0。 |
| | | 1 | DSG_ON | RW | 0 | 放电 MOS 管控制。1=开启放电通路；0=关闭。故障发生后不会自动恢复，需软件写入 1。 |
| | | 0 | CHG_ON | RW | 0 | 充电 MOS 管控制。1=开启充电通路；0=关闭。故障发生后不会自动恢复，需软件写入 1。 |

### 2. 保护配置寄存器 (Protection Configuration)

用于设置过流、短路的阈值和延时，以及过压、欠压的阈值和延时。

| 寄存器名称 | 地址 | 位 (Bit) | 名称 | 功能详解 |
| --- | ---- | --- | --- | --- |
| PROTECT1 | 0x06 | 7 | RSNS | 量程倍增。0=低量程 (OCD/SCD 阈值较低)；1=高量程 (阈值 x2)。 配合下方阈值位使用。 |
| (短路保护1) | | 6 | RSVD | 保留。 |
| | | 5 | RSVD | 保留。 |
| | | 4-3 | SCD_DELAY  | 短路延时设置: `00`=70µs, `01`=100µs, `10`=200µs, `11`=400µs。 |
| | | 2-0 | SCD_THRESH | 短路阈值设置 (单位 mV，取决于 RSNS 位): 若 RSNS=0: `000`=22mV ... `111`=100mV 若 RSNS=1: `000`=44mV ... `111`=200mV |
| PROTECT2 | 0x07 | 7 | RSVD | 保留。 |
| (过流保护2) | | 6-4 | OCD_DELAY  | 过流延时设置: `000`=8ms ... `111`=1280ms (具体查表，呈倍数增长)。 |
| | | 3-0 | OCD_THRESH | 过流阈值设置 (单位 mV，取决于 RSNS 位): 若 RSNS=0: `0000`=8mV ... `1111`=50mV 若 RSNS=1: `0000`=17mV ... `1111`=100mV |
| PROTECT3 | 0x08 | 7-6 | UV_DELAY | 欠压延时设置: `00`=1s, `01`=4s, `10`=8s, `11`=16s。 |
| (压延保护延时) | | 5-4 | OV_DELAY | 过压延时设置: `00`=1s, `01`=2s, `10`=4s, `11`=8s。 |
| | | 3-0 | RSVD | 保留，保持默认。 |
| OV_TRIP | 0x09 | 7-0 | OV_THRESH  | 过压阈值中间8位。 实际阈值为 `10` + [这8位] + `1000` (共14位 ADC 值)。 需结合 ADCGAIN/OFFSET 计算具体电压值 (约 3.15V~4.7V)。默认 0xAC。 |
| UV_TRIP | 0x0A | 7-0 | UV_THRESH  | 欠压阈值中间8位。 实际阈值为 `01` + [这8位] + `0000` (共14位 ADC 值)。 需结合 ADCGAIN/OFFSET 计算具体电压值 (约 1.58V~3.1V)。默认 0x97。 |
| CC_CFG | 0x0B | 7-6 | RSVD | 保留。 |
| (CC 配置) | | 5-0 | CC_CFG | 必须写入 0x19 以获得最佳库仑计数器性能。 |

### 3. 数据读取寄存器 (Data Readout Registers)

这些寄存器只读，存储最新的测量数据。读取时应连续读取 HI 和 LO 字节。

| 寄存器组 | 地址范围 | 说明 |
| --- | --- | --- |
| VC1 ~ VC5 | 0x0C - 0x15 | 电芯电压 1-5。每节电芯占用 2 字节 (HI/LO)。格式为 14-bit ADC 值。 例如：VC1_HI (0x0C), VC1_LO (0x0D)。 |
| VC6 ~ VC10  | 0x16 - 0x1F | 电芯电压 6-10 (仅 BQ76930/40 有效)。 |
| VC11 ~ VC15 | 0x20 - 0x29 | 电芯电压 11-15 (仅 BQ76940 有效)。 |
| BAT | 0x2A - 0x2B | 电池组总电压。16-bit 值，LSB ≈ 1.532mV。 |
| TS1 | 0x2C - 0x2D | 温度 1。可配置为外部热敏电阻或内部芯片温度。14-bit ADC 值。  |
| TS2 | 0x2E - 0x2F | 温度 2 (仅 BQ76930/40 有效)。 |
| TS3 | 0x30 - 0x31 | 温度 3 (仅 BQ76940 有效)。 |
| CC | 0x32 - 0x33 | 库仑计数器 (电流积分)。16-bit 有符号数 (2's complement)。 电压值 = 数值 × 8.44µV。电流 = 电压 / Rsense。 |

### 4. 校准系数寄存器 (Calibration Coefficients)

这些寄存器只读，存储出厂校准的 Gain 和 Offset，用于将 ADC 原始数据转换为精确电压。

| 寄存器名称 | 地址 | 位 (Bit) | 说明 |
| --- | ---- | --- | --- |
| ADCGAIN1 | 0x50 | 4-3 | ADC Gain 高2位。 |
| ADCGAIN2 | 0x59 | 7-5 | ADC Gain 低3位。 组合成 5-bit 值，计算公式： $ Gain (\mu V/LSB) = 365 + Value $ 。范围 365~396。 |
| ADCOFFSET  | 0x51 | 7-0 | ADC Offset。8-bit 有符号数 (mV)。范围 -128mV ~ +127mV。 |

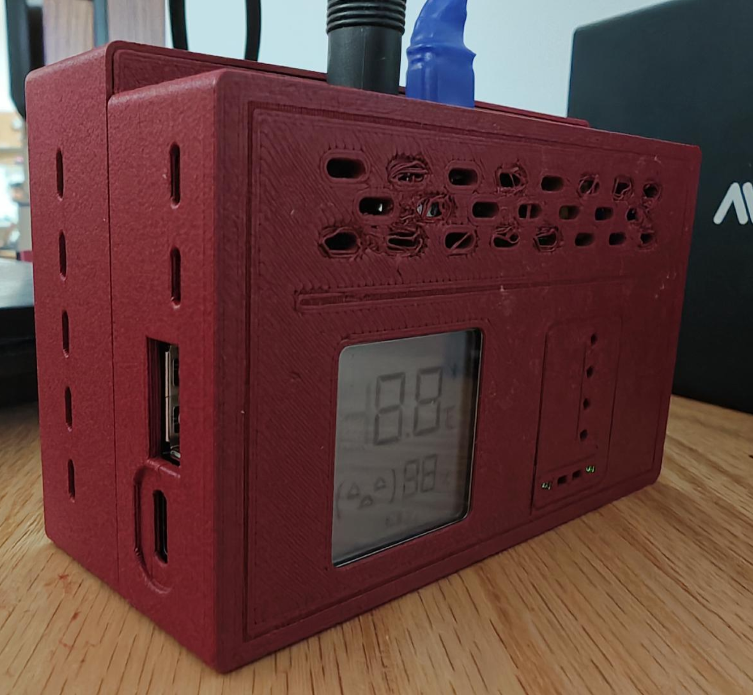
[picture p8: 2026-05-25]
hardware/v2/实物图.png

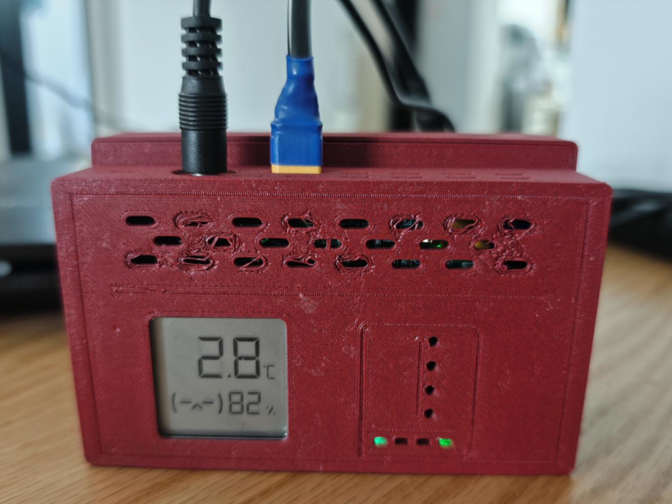
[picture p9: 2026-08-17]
hardware/v2/7c027a9a-14f9-4617-bbe4-73dce2b325db.png

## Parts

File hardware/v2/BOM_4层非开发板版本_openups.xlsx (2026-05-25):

Quantity | Designator | Footprint | Value | Comment | Device | Manufacturer | Manufacturer Part | Supplier | Supplier Part | Primary Category | Secondary Category | Pin Count | Name
1 | BUZZER1 | BUZ-TH_BD12.0-P7.60-D0.6-FD | 2.3kHz | 2.3kHz | TMB12A03 | 华能 | TMB12A03 | LCSC | C96222 | 音频器件/振动马达 | 蜂鸣器 | 2 | 2.3kHz
1 | C0 | C0603 | 2.2uF | 2.2uF | CL10A225KA8NNNC | SAMSUNG(三星) | CL10A225KA8NNNC | LCSC | C57895 | 电容 | 贴片电容(MLCC) | 2 | 2.2uF
23 | C1,C2,C3,C4,C12,C13,C14,C18,C19,C20,C26,C27,C28,C29,C30,C31,C32,C33,C41,C44,C45,C47,C48 | C0603 | 100nF | 100nF | CGA0603X7R104K500JT,FCC0603B104K500CT | FOJAN(富捷),HRE(芯声) | CGA0603X7R104K500JT,FCC0603B104K500CT | LCSC | C5137636,C6119867 | 电容 | 贴片电容(MLCC) | 2 | 100nF
5 | C5,C6,C34,C36,C37 | C0603 | 1uF | 1uF | CGA0603X5R105K500JT | HRE(芯声) | CGA0603X5R105K500JT | LCSC | C6119852 | 电容 | 贴片电容(MLCC) | 2 | 1uF
2 | C7,C16 | C0603 | 47nF | 47nF | CL10B473KB8NNNC | SAMSUNG(三星) | CL10B473KB8NNNC | LCSC | C1622 | 电容 | 贴片电容(MLCC) | 2 | 47nF
5 | C8,C9,C24,C25,C46 | C0603 | 10uF | 10uF | CGA0603X5R106K100JT,CL10A106MA8NRNC | HRE(芯声),SAMSUNG(三星) | CGA0603X5R106K100JT,CL10A106MA8NRNC | LCSC | C96446,C6119842 | 电容 | 贴片电容(MLCC) | 2 | 10uF
5 | C10,C11,C15,C38,C40 | C0603 | 100pF | 100pF | CL10C101JB8NNNC | SAMSUNG(三星) | CL10C101JB8NNNC | LCSC | C14858 | 电容 | 贴片电容(MLCC) | 2 | 100pF
1 | C17 | C0603 | 1nF | 1nF | CL10B102KB8NNNC | SAMSUNG(三星) | CL10B102KB8NNNC | LCSC | C1588 | 电容 | 贴片电容(MLCC) | 2 | 1nF
2 | C21,C22 | C0603 | 22uF | 22uF | CL10A226MP8NUNE | SAMSUNG(三星) | CL10A226MP8NUNE | LCSC | C86295 | 电容 | 贴片电容(MLCC) | 2 | 22uF
1 | C23 | C0603 | 33pF | 33pF | CL10C330JB8NNNC | SAMSUNG(三星) | CL10C330JB8NNNC | LCSC | C1663 | 电容 | 贴片电容(MLCC) | 2 | 33pF
1 | C35 | C0603 | 4.7uF | 4.7uF | CGA0603X5R475K250JT | HRE(芯声) | CGA0603X5R475K250JT | LCSC | C6119856 | 电容 | 贴片电容(MLCC) | 2 | 4.7uF
3 | C39,C42,C43 | C0603 | 10nF | 10nF | CL10B103KB8NNNC | SAMSUNG(三星) | CL10B103KB8NNNC | LCSC | C1589 | 电容 | 贴片电容(MLCC) | 2 | 10nF
1 | CN1 | CONN-TH_6P-P2.50_HCZZ0139-6 |  | HX-XH2.54-6PWZ | HX-XH2.54-6PWZ | hanxia(韩下) | HX-XH2.54-6PWZ | LCSC | C48641718 | 连接器 | 线对板针座 | 6 | HX-XH2.54-6PWZ
1 | CN2 | CONN-TH_HX-XH2.54-2PWZ |  | HX-XH2.54-2PWZ | HX-XH2.54-2PWZ | hanxia(韩下) | HX-XH2.54-2PWZ | LCSC | C48641714 | 连接器 | 线对板针座 | 2 | HX-XH2.54-2PWZ
1 | CN3 | CONN-TH_XT30PW-M |  | XT30PW-M30.G.Y | XT30PW-M30.G.Y | AMASS(艾迈斯) | XT30PW-M30.G.Y | LCSC | C431092 | 工控电气 | 插头 | 4 | XT30PW-M30.G.Y
1 | CN4 | CONN-SMD_4P-P1.00_WAFER-SH1.0-4PWB |  | WAFER-SH1.0-4PWB | WAFER-SH1.0-4PWB | XUNPU(讯普) | WAFER-SH1.0-4PWB | LCSC | C3029343 | 连接器 | 线对板针座 | 6 | WAFER-SH1.0-4PWB
1 | Csys | CAP-SMD_BD6.3-L6.6-W6.6-LS7.3-FD-H7.7 | 220uF | 220uF | JVJ25V220M6x8 | JIERR(捷而瑞) | JVJ25V220M6x8 | LCSC | C46550404 | 电容 | 贴片型铝电解电容 | 2 | 220uF
1 | D1 | SOD-123FL_L2.7-W1.8-LS3.8-RD |  | SMF24A | SMF24A_C19077514 | R+O(宏嘉诚) | SMF24A | LCSC | C19077514 | 三极管/MOS管/晶体管 | 静电和浪涌保护(TVS/ESD) | 2 | SMF24A
1 | D2 | SOT-23-3_L2.9-W1.6-P1.90-LS2.8-BR |  | BAT54C,215 | BAT54C,215 | Nexperia(安世) | BAT54C,215 | LCSC | C37704 | 二极管 | 肖特基二极管 | 3 | BAT54C,215
2 | D3,D4 | SOD-323_L1.7-W1.3-LS2.6-RD-1 |  | BAT54WS | BAT54WS_C7502694 | R+O(宏嘉诚) | BAT54WS | LCSC | C7502694 | 二极管 | 肖特基二极管 | 2 | BAT54WS
1 | DC1 | DC-IN-TH_HC-DC-007B-2.5 |  | HC-DC-007B-2.5 | HC-DC-007B-2.5 | HCTL(华灿天禄) | HC-DC-007B-2.5 | LCSC | C3010538 | 连接器 | DC电源连接器 | 6 | HC-DC-007B-2.5
1 | DCout | CONN-TH_XT30PW-F-1 |  | XT30PW-F20.G.Y | XT30PW-F20.G.Y | AMASS(艾迈斯) | XT30PW-F20.G.Y | LCSC | C2913282 | 工控电气 | 电源连接器/插接器 | 4 | XT30PW-F20.G.Y
1 | H1 | HDR-TH_4P-P2.54-V-M |  | PZ254V-11-04P | PZ254V-11-04P | XFCN(兴飞) | PZ254V-11-04P | LCSC | C2691448 | 连接器 | 排针 | 4 | PZ254V-11-04P
1 | L1 | IND-SMD_L5.4-W5.2_FXL05XX | 3.3uH | 3.3uH | FXL0530-3R3-M | cjiang(长江微电) | FXL0530-3R3-M | LCSC | C475518 | 电感/线圈/变压器 | 功率电感 | 2 | 3.3uH
1 | L2 | IND-SMD_L5.4-W5.2_FXL0530 | 4.7uH | 4.7uH | FXL0530-4R7-M | cjiang(长江微电) | FXL0530-4R7-M | LCSC | C177246 | 电感/线圈/变压器 | 功率电感 | 2 | 4.7uH
1 | LED1 | LED0603-RD |  | GL0603UG01 | GL0603UG01 | Guiguang light(桂光光电) | GL0603UG01 | LCSC | C51933293 | 光电器件 | 发光二极管/LED | 2 | GL0603UG01
1 | LED2 | LED0603-FD |  | GL0603UR01 | GL0603UR01 | Guiguang light(桂光光电) | GL0603UR01 | LCSC | C51933292 | 光电器件 | 发光二极管/LED | 2 | GL0603UR01
1 | LED3 | LED0603-RD_BLUE |  | GL0603UB01 | GL0603UB01 | Guiguang light(桂光光电) | GL0603UB01 | LCSC | C51933294 | 光电器件 | 发光二极管/LED | 2 | GL0603UB01
1 | LED4 | LED-SMD_4P-L1.6-W0.8-RD_1 |  | XL-1608SURUGC | XL-1608SURUGC | XINGLIGHT(成兴光) | XL-1608SURUGC | LCSC | C5349934 | 光电器件 | 发光二极管/LED | 4 | XL-1608SURUGC
3 | Q1,Q2,Q6 | SOP-8_L5.0-W4.0-P1.27-LS6.0-BL |  | FDS6680A | FDS6680A | onsemi(安森美) | FDS6680A | LCSC | C87668 | 三极管/MOS管/晶体管 | 场效应管(MOSFET) | 8 | FDS6680A
4 | Q3,Q4,Q7,Q8 | PDFN-8_L3.1-W3.1-P0.65-LS3.4-BL |  | SIS412DN-T1-GE3-ES | SIS412DN-T1-GE3-ES | ElecSuper(静芯) | SIS412DN-T1-GE3-ES | LCSC | C21713860 | 三极管/MOS管/晶体管 | 场效应管(MOSFET) | 9 | SIS412DN-T1-GE3-ES
1 | Q5 | SC-70-3_L2.0-W1.3-P0.65-LS2.1-BL |  | BSS138W | BSS138W_C890266 | onsemi(安森美) | BSS138W | LCSC | C890266 |  |  | 3 | BSS138W
1 | Q9 | SOT-23-3_L2.9-W1.3-P1.90-LS2.4-BR-1 |  | BSS84 | BSS84_C7420340 | R+O(宏嘉诚) | BSS84 | LCSC | C7420340 | 三极管/MOS管/晶体管 | 场效应管(MOSFET) | 3 | BSS84
1 | Q10 | SOT-23-3_L2.9-W1.3-P1.90-LS2.4-BR |  | AO3401 | AO3401_C5224195 | ElecSuper(静芯) | AO3401 | LCSC | C5224195 | 三极管/MOS管/晶体管 | 场效应管(MOSFET) | 3 | AO3401
1 | R0 | R0603 | 2Ω | 2Ω | 0603WAF200KT5E | UNI-ROYAL(厚声) | 0603WAF200KT5E | LCSC | C22977 | 电阻 | 贴片电阻 | 2 | 2Ω
2 | R1,R18 | R0603 | 499kΩ | 499kΩ | 0603WAF4993T5E | UNI-ROYAL(厚声) | 0603WAF4993T5E | LCSC | C26751 | 电阻 | 贴片电阻 | 2 | 499kΩ
1 | R2 | R0603 | 133kΩ | 133kΩ | 0603WAF1333T5E | UNI-ROYAL(厚声) | 0603WAF1333T5E | LCSC | C22870 | 电阻 | 贴片电阻 | 2 | 133kΩ
6 | R3,R9,R14,R15,R20,R42 | R0603 | 10Ω | 10Ω | 0603WAF100JT5E | UNI-ROYAL(厚声) | 0603WAF100JT5E | LCSC | C22859 | 电阻 | 贴片电阻 | 2 | 10Ω
1 | R4 | R0603 | 316kΩ | 316kΩ | 0603WAF3163T5E | UNI-ROYAL(厚声) | 0603WAF3163T5E | LCSC | C25814 | 电阻 | 贴片电阻 | 2 | 316kΩ
3 | R5,R44,R48 | R0603 | 100kΩ | 100kΩ | 0603WAF1003T5E | UNI-ROYAL(厚声) | 0603WAF1003T5E | LCSC | C25803 | 电阻 | 贴片电阻 | 2 | 100kΩ
5 | R6,R10,R11,R55,R67 | R0603 | 4.7kΩ | 4.7kΩ | 0603WAF4701T5E | UNI-ROYAL(厚声) | 0603WAF4701T5E | LCSC | C23162 | 电阻 | 贴片电阻 | 2 | 4.7kΩ
1 | R7 | R0603 | 14.3kΩ | 14.3kΩ | FRC0603F1432TS | FOJAN(富捷) | FRC0603F1432TS | LCSC | C2933145 | 电阻 | 贴片电阻 | 2 | 14.3kΩ
1 | R8 | R0603 | 3MΩ | 3MΩ | 0603WAF3004T5E | UNI-ROYAL(厚声) | 0603WAF3004T5E | LCSC | C23156 | 电阻 | 贴片电阻 | 2 | 3MΩ
5 | R12,R31,R32,R33,R46 | R0603 | 1MΩ | 1MΩ | 0603WAF1004T5E | UNI-ROYAL(厚声) | 0603WAF1004T5E | LCSC | C22935 | 电阻 | 贴片电阻 | 2 | 1MΩ
16 | R13,R16,R24,R25,R28,R41,R45,R50,R51,R62,R63,R64,R68,R69,R76,R77 | R0603 | 10kΩ | 10kΩ | FRC0603F1002TS | FOJAN(富捷) | FRC0603F1002TS | LCSC | C2906982 | 电阻 | 贴片电阻 | 2 | 10kΩ
1 | R17 | R0603 | 866kΩ | 866kΩ | FRC0603F8663TS | FOJAN(富捷) | FRC0603F8663TS | LCSC | C5126056 | 电阻 | 贴片电阻 | 2 | 866kΩ
1 | R19 | R0603 | 9.09kΩ | 9.09kΩ | FRC0603F9091TS | FOJAN(富捷) | FRC0603F9091TS | LCSC | C2930134 | 电阻 | 贴片电阻 | 2 | 9.09kΩ
1 | R21 | R0603 | 20kΩ | 20kΩ | 0603WAF2002T5E | UNI-ROYAL(厚声) | 0603WAF2002T5E | LCSC | C4184 | 电阻 | 贴片电阻 | 2 | 20kΩ
2 | R22,R56 | R0603 | 40.2kΩ | 40.2kΩ | FRC0603F4022TS | FOJAN(富捷) | FRC0603F4022TS | LCSC | C2933218 | 电阻 | 贴片电阻 | 2 | 40.2kΩ
1 | R23 | R0603 | 7.5kΩ | 7.5kΩ | 0603WAF7501T5E | UNI-ROYAL(厚声) | 0603WAF7501T5E | LCSC | C23234 | 电阻 | 贴片电阻 | 2 | 7.5kΩ
1 | R26 | R1206 | 0Ω | 0Ω | RE1206F1R000 | JIERR(捷而瑞) | RE1206F1R000 | LCSC | C46961765 | 电阻 | 电流采样电阻/分流器 | 2 | 0Ω
6 | R29,R30,R40,R52,R61,R78 | R0603 | 100Ω | 100Ω | 0603WAF1000T5E,FRC0603F1000TS | FOJAN(富捷),UNI-ROYAL(厚声) | 0603WAF1000T5E,FRC0603F1000TS | LCSC | C22775,C2906981 | 电阻 | 贴片电阻 | 2 | 100Ω
9 | R34,R35,R36,R37,R38,R39,R53,R54,R57 | R0603 | 1kΩ | 1kΩ | 0603WAF1001T5E | UNI-ROYAL(厚声) | 0603WAF1001T5E | LCSC | C21190 | 电阻 | 贴片电阻 | 2 | 1kΩ
2 | R43,R47 | R0603 | 910kΩ | 910kΩ | FRC0603F9103TS | FOJAN(富捷) | FRC0603F9103TS | LCSC | C2907075 | 电阻 | 贴片电阻 | 2 | 910kΩ
1 | R49 | R0603 |  | HNTC0603-103F3450FA | HNTC0603-103F3450FA | R+O(宏嘉诚) | HNTC0603-103F3450FA | LCSC | C49247665 | 传感器 | NTC热敏电阻 | 2 | HNTC0603-103F3450FA
2 | R58,R60 | R0603 | 330Ω | 330Ω | 0603WAF3300T5E | UNI-ROYAL(厚声) | 0603WAF3300T5E | LCSC | C23138 | 电阻 | 贴片电阻 | 2 | 330Ω
1 | R59 | R0603 | 47Ω | 47Ω | 0603WAF470JT5E | UNI-ROYAL(厚声) | 0603WAF470JT5E | LCSC | C23182 | 电阻 | 贴片电阻 | 2 | 47Ω
2 | R70,R72 | R0603 | 5.1kΩ | 5.1kΩ | FRC0603F5101TS | FOJAN(富捷) | FRC0603F5101TS | LCSC | C2907044 | 电阻 | 贴片电阻 | 2 | 5.1kΩ
2 | R71,R73 | R0603 | 22Ω | 22Ω | FRC0603F22R0TS | FOJAN(富捷) | FRC0603F22R0TS | LCSC | C2930077 | 电阻 | 贴片电阻 | 2 | 22Ω
2 | R74,R75 | R0402 | 0Ω | 0Ω | FRC0402F0000TS | FOJAN(富捷) | FRC0402F0000TS | LCSC | C2906858 | 电阻 | 贴片电阻 | 2 | 0Ω
2 | RAC,RSR | R2512 | 10mΩ | 10mΩ | RE2512F3R010 | JIERR(捷而瑞) | RE2512F3R010 | LCSC | C46961753 | 电阻 | 电流采样电阻/分流器 | 2 | 10mΩ
1 | Rsns | R2512 | 5mΩ | 5mΩ | JER2512F3R005 | JIERR(捷而瑞) | JER2512F3R005 | LCSC | C46634460 | 电阻 | 电流采样电阻/分流器 | 2 | 5mΩ
4 | SWactivate,SWreset,SW_mcuBoot,SW_mcuReset | SW-SMD_4P-L5.1-W5.1-P3.70-LS6.5-TL_H1.5 |  | TS-1187A-B-A-B | TS-1187A-B-A-B | XKB Connection(中国星坤) | TS-1187A-B-A-B | LCSC | C318884 | 按键/开关 | 轻触开关 | 4 | TS-1187A-B-A-B
1 | U1 | WQFN-28_L4.0-W4.0-P0.40-BL-EP |  | BQ24780SRUYR | BQ24780SRUYR | TI(德州仪器) | BQ24780SRUYR | LCSC | C882400 |  |  | 29 | BQ24780SRUYR
1 | U2 | TSOT-23-8_L2.9-W1.6-P0.65-LS2.8-BL |  | MP2315SGJ-Z | MP2315SGJ-Z | MPS(芯源) | MP2315SGJ-Z | LCSC | C3031493 | 电源管理 | DC-DC电源芯片 | 8 | MP2315SGJ-Z
1 | U3 | SOT-223-3_L6.5-W3.4-P2.30-LS7.0-BR |  | AMS1117-3.3 | AMS1117-3.3_C6186 | AMS | AMS1117-3.3 | LCSC | C6186 | 电源管理 | 线性稳压器(LDO) | 4 | AMS1117-3.3
1 | U4 | TSSOP-20_L6.5-W4.4-P0.65-LS6.4-BL |  | BQ7692003PWR | BQ7692003PWR | TI(德州仪器) | BQ7692003PWR | LCSC | C601650 | 电源管理 | 电池管理 | 20 | BQ7692003PWR
2 | U5,U8 | SOP-4_L4.4-W2.8-P1.27-LS7.0-BR |  | TLP293(GB-TPL,E | TLP293(GB-TPL,E | TOSHIBA(东芝) | TLP293(GB-TPL,E | LCSC | C77656 | 光耦 | 晶体管输出光耦 | 4 | TLP293(GB-TPL,E
1 | U6 | SOIC-8_L4.9-W3.9-P1.27-LS6.0-TL |  | ISO1640BDR | ISO1640BDR | TI(德州仪器) | ISO1640BDR | LCSC | C5122339 | 信号隔离器件 | 隔离式I2C | 8 | ISO1640BDR
1 | U7 | WIRELM-SMD_ESP32-S3-WROOM-1 |  | ESP32-S3-WROOM-1-N16R8 | ESP32-S3-WROOM-1-N16R8 | ESPRESSIF(乐鑫) | ESP32-S3-WROOM-1-N16R8 | LCSC | C2913202 | 物联网/通信模块 | WiFi模块 | 49 | ESP32-S3-WROOM-1-N16R8
1 | U9 | DFN-4_L2.0-W2.0-P1.00-BL-EP |  | SHTC3-TR-10KS | SHTC3-TR-10KS | Sensirion(瑞士盛思锐) | SHTC3-TR-10KS | none | C2880044 | 传感器 | 温湿度传感器 | 5 | SHTC3-TR-10KS
1 | USB1 | USB-A-TH_AF-WJDG |  | AF 90° WJDG | AF 90° WJDG | SHOU HAN(首韩) | AF 90° WJDG | LCSC | C456018 | 连接器 | USB连接器 | 6 | AF 90° WJDG
1 | USB3 | USB-C-SMD_TYPE-C-6PIN-2MD-073 |  | TYPE-C 16PIN 2MD(073) | TYPE-C 16PIN 2MD(073) | SHOU HAN(首韩) | TYPE-C 16PIN 2MD(073) | LCSC | C2765186 | 连接器 | USB连接器 | 16 | TYPE-C 16PIN 2MD(073)

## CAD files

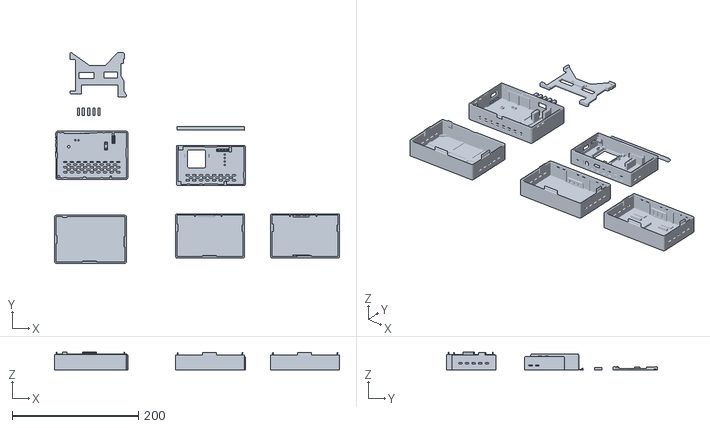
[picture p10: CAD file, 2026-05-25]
hardware/v2/ups外壳.stl
451.7 x 334.3 x 28.4

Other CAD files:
hardware/v2/ups外壳.skp

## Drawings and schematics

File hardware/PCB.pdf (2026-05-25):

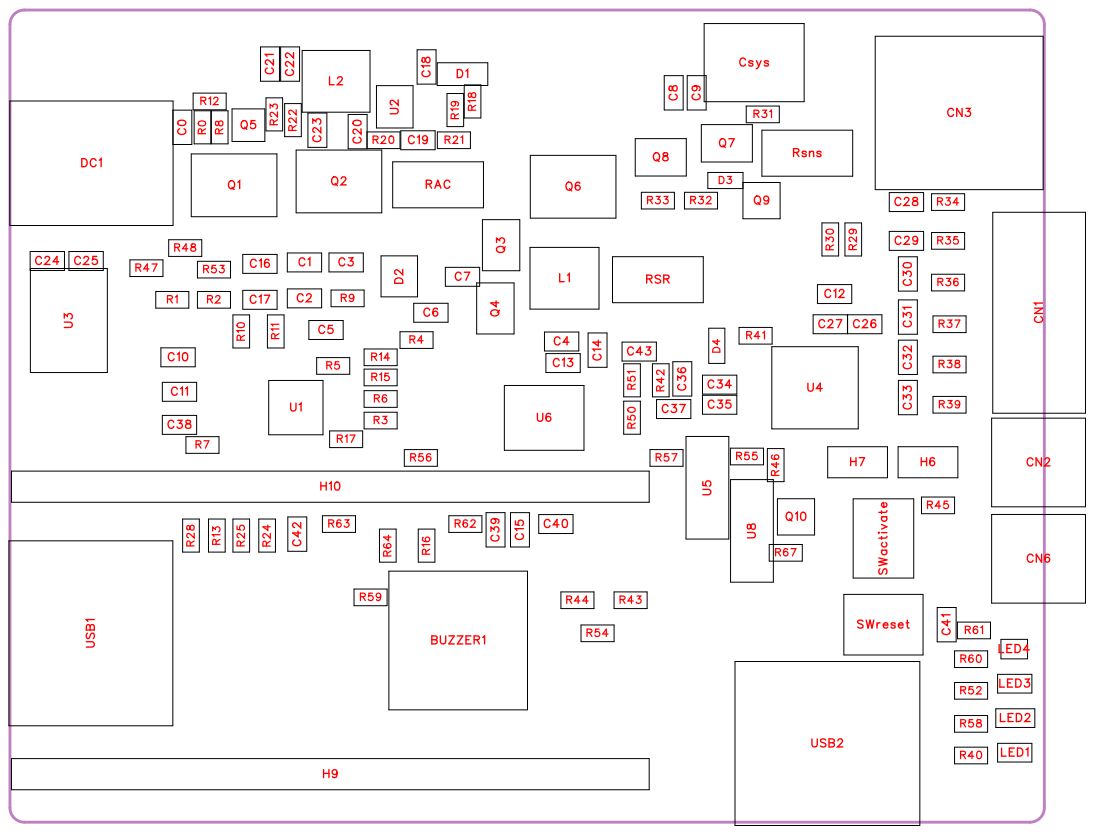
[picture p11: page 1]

C24 | C25 | R48 R47 R53 | C16 | C1 | C3 | L1 | R35 RSR

R52 | LED3

R58 | LED2

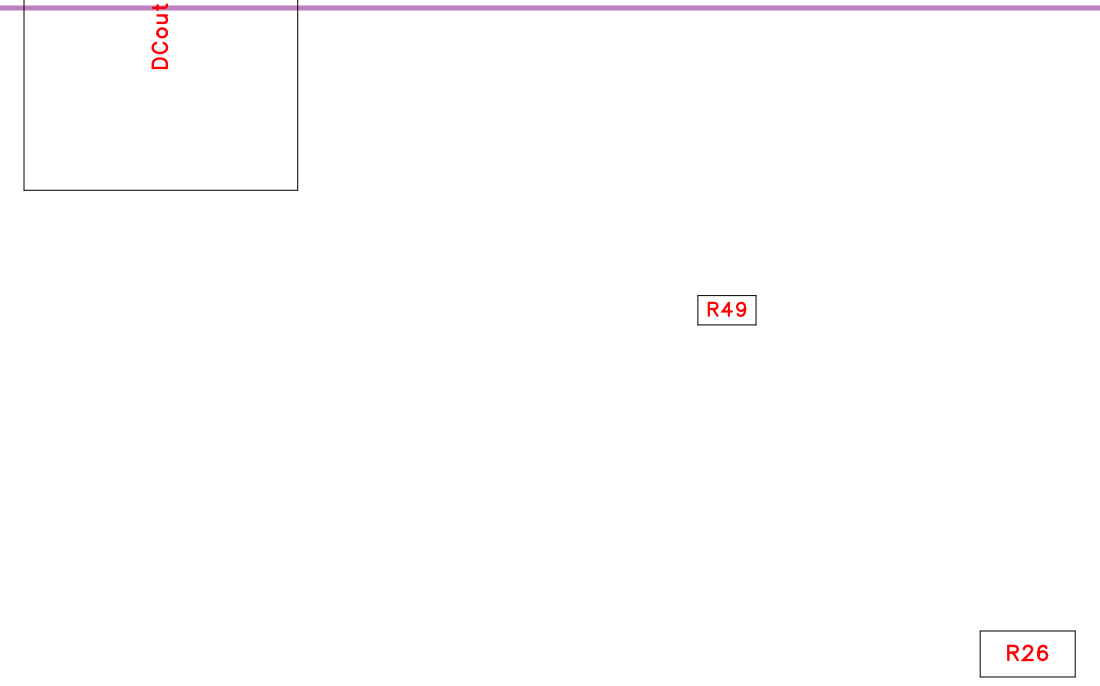
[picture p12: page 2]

Quantity | Designator | Footprint | Value | Comment | Device
1 | BUZZER1 | BUZ-TH_BD 12.0-P7.60-D 0.6-FD | 2.3kHz | 2.3kHz | TMB12A03
1 | C0 | C0603 | 2.2uF | 2.2uF | CL10A225KA 8NNNC
19 | C1,C2,C3,C4,C12,C13,C14, C18,C19,C20,C26,C27,C28 ,C29,C30,C31,C32,C33,C4 1 | C0603 | 100nF | 100nF | FCC0603B10 4K500CT
5 | C5,C6,C34,C36,C37 | C0603 | 1uF | 1uF | CGA0603X5 R105K500JT
2 | C7,C16 | C0603 | 47nF | 47nF | CL10B473KB 8NNNC
4 | C8,C9,C24,C25 | C0603 | 10uF | 10uF | CGA0603X5 R106K100JT ,CL10A106M A8NRNC
5 | C10,C11,C15,C38,C40 | C0603 | 100pF | 100pF | CL10C101JB 8NNNC
1 | C17 | C0603 | 1nF | 1nF | CL10B102KB 8NNNC
2 | C21,C22 | C0603 | 22uF | 22uF | CL10A226M P8NUNE
1 | C23 | C0603 | 33pF | 33pF | CL10C330JB 8NNNC
1 | C35 | C0603 | 4.7uF | 4.7uF | CGA0603X5 R475K250JT
3 | C39,C42,C43 | C0603 | 10nF | 10nF | CL10B103KB 8NNNC
1 | CN1 | CONN-TH_6 P-P2.50_HC ZZ0139-6 | | HX-XH2.54-6 PWZ | HX-XH2.54-6 PWZ
2 | CN2,CN6 | CONN-TH_H X-XH2.54-2P WZ | | HX-XH2.54-2 PWZ | HX-XH2.54-2 PWZ
1 | CN3 | CONN-TH_X T30PW-M | | XT30PW-M3 0.G.Y | XT30PW-M3 0.G.Y
1 | Csys | CAP-SMD_B D6.3-L6.6-W 6.6-LS7.3-FD -H7.7 | 220uF | 220uF | JVJ25V220M 6x8
1 | D1 | SOD-123FL_ L2.7-W1.8-L S3.8-RD | | SMF24A | SMF24A_C1 9077514
1 | D2 | SOT-23-3_L2 .9-W1.6-P1.9 0-LS2.8-BR | | BAT54C,215 | BAT54C,215
2 | D3,D4 | SOD-323_L1 .7-W1.3-LS2. 6-RD-1 | | BAT54WS | BAT54WS_C 7502694

1 | DC1 | DC-IN-TH_H C-DC-007B-2 .5 | | HC-DC-007B -2.5 | HC-DC-007B -2.5
1 | DCout | CONN-TH_X T30PW-F-1 | | XT30PW-F20 .G.Y | XT30PW-F20 .G.Y
2 | H6,H7 | HDR-TH_2P-P2.54-V-M | | PZ254V-11-0 2P | PZ254V-11-0 2P
2 | H9,H10 | HDR-TH_22 P-P2.54-V-F | | CS-1165SDI G-1*22 | CS-1165SDI G-1*22
1 | L1 | IND-SMD_L5 .4-W5.2_FXL 05XX | 3.3uH | 3.3uH | FXL0530-3R 3-M
1 | L2 | IND-SMD_L5 .4-W5.2_FXL 0530 | 4.7uH | 4.7uH | FXL0530-4R 7-M
1 | LED1 | LED0603-RD | | GL0603UG0 1 | GL0603UG0 1
1 | LED2 | LED0603-FD | | GL0603UR0 1 | GL0603UR0 1
1 | LED3 | LED0603-RD _BLUE | | GL0603UB01 | GL0603UB01
1 | LED4 | LED-SMD_4 P-L1.6-W0.8-RD_1 | | XL-1608SUR UGC | XL-1608SUR UGC
3 | Q1,Q2,Q6 | SOP-8_L5.0-W4.0-P1.27-LS6.0-BL | | FDS6680A | FDS6680A
4 | Q3,Q4,Q7,Q8 | PDFN-8_L3. 1-W3.1-P0.6 5-LS3.4-BL | | SIS412DN-T 1-GE3-ES | SIS412DN-T 1-GE3-ES
1 | Q5 | SC-70-3_L2. 0-W1.3-P0.6 5-LS2.1-BL | | BSS138W | BSS138W_C 890266
1 | Q9 | SOT-23-3_L2 .9-W1.3-P1.9 0-LS2.4-BR-1 | | BSS84 | BSS84_C742 0340
1 | Q10 | SOT-23-3_L2 .9-W1.3-P1.9 0-LS2.4-BR | | AO3401 | AO3401_C52 24195
1 | R0 | R0603 | 2 | 2 | 0603WAF20 0KT5E
2 | R1,R18 | R0603 | 499k | 499k | 0603WAF49 93T5E
1 | R2 | R0603 | 133k | 133k | 0603WAF13 33T5E
6 | R3,R9,R14,R15,R20,R42 | R0603 | 10 | 10 | 0603WAF10 0JT5E
1 | R4 | R0603 | 316k | 316k | 0603WAF31 63T5E

3 | R5,R44,R48 | R0603 | 100k | 100k | 0603WAF10 03T5E
5 | R6,R10,R11,R55,R67 | R0603 | 4.7k | 4.7k | 0603WAF47 01T5E
1 | R7 | R0603 | 14.3k | 14.3k | FRC0603F14 32TS
1 | R8 | R0603 | 3M | 3M | 0603WAF30 04T5E
5 | R12,R31,R32,R33,R46 | R0603 | 1M | 1M | 0603WAF10 04T5E
12 | R13,R16,R24,R25,R28,R41 ,R45,R50,R51,R62,R63,R6 4 | R0603 | 10k | 10k | FRC0603F10 02TS
1 | R17 | R0603 | 866k | 866k | FRC0603F86 63TS
1 | R19 | R0603 | 9.09k | 9.09k | FRC0603F90 91TS
1 | R21 | R0603 | 20k | 20k | 0603WAF20 02T5E
2 | R22,R56 | R0603 | 40.2k | 40.2k | FRC0603F40 22TS
1 | R23 | R0603 | 7.5k | 7.5k | 0603WAF75 01T5E
1 | R26 | R1206 | 0 | 0 | RE1206F1R0 00
5 | R29,R30,R40,R52,R61 | R0603 | 100 | 100 | 0603WAF10 00T5E
9 | R34,R35,R36,R37,R38,R39 ,R53,R54,R57 | R0603 | 1k | 1k | 0603WAF10 01T5E
2 | R43,R47 | R0603 | 910k | 910k | FRC0603F91 03TS
1 | R49 | R0603 | | HNTC0603-1 03F3450FA | HNTC0603-1 03F3450FA
2 | R58,R60 | R0603 | 330 | 330 | 0603WAF33 00T5E
1 | R59 | R0603 | 47 | 47 | 0603WAF47 0JT5E
2 | RAC,RSR | R2512 | 10m | 10m | RE2512F3R0 10
1 | Rsns | R2512 | 5m | 5m | JER2512F3R 005
2 | SWactivate,SWreset | SW-SMD_4P -L5.1-W5.1-P 3.70-LS6.5-T L_H1.5 | | TS-1187A-B-A-B | TS-1187A-B-A-B
1 | U1 | WQFN-28_L 4.0-W4.0-P0. 40-BL-EP | | BQ24780SR UYR | BQ24780SR UYR
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

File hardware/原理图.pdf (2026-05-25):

## NMOS

## NMOS

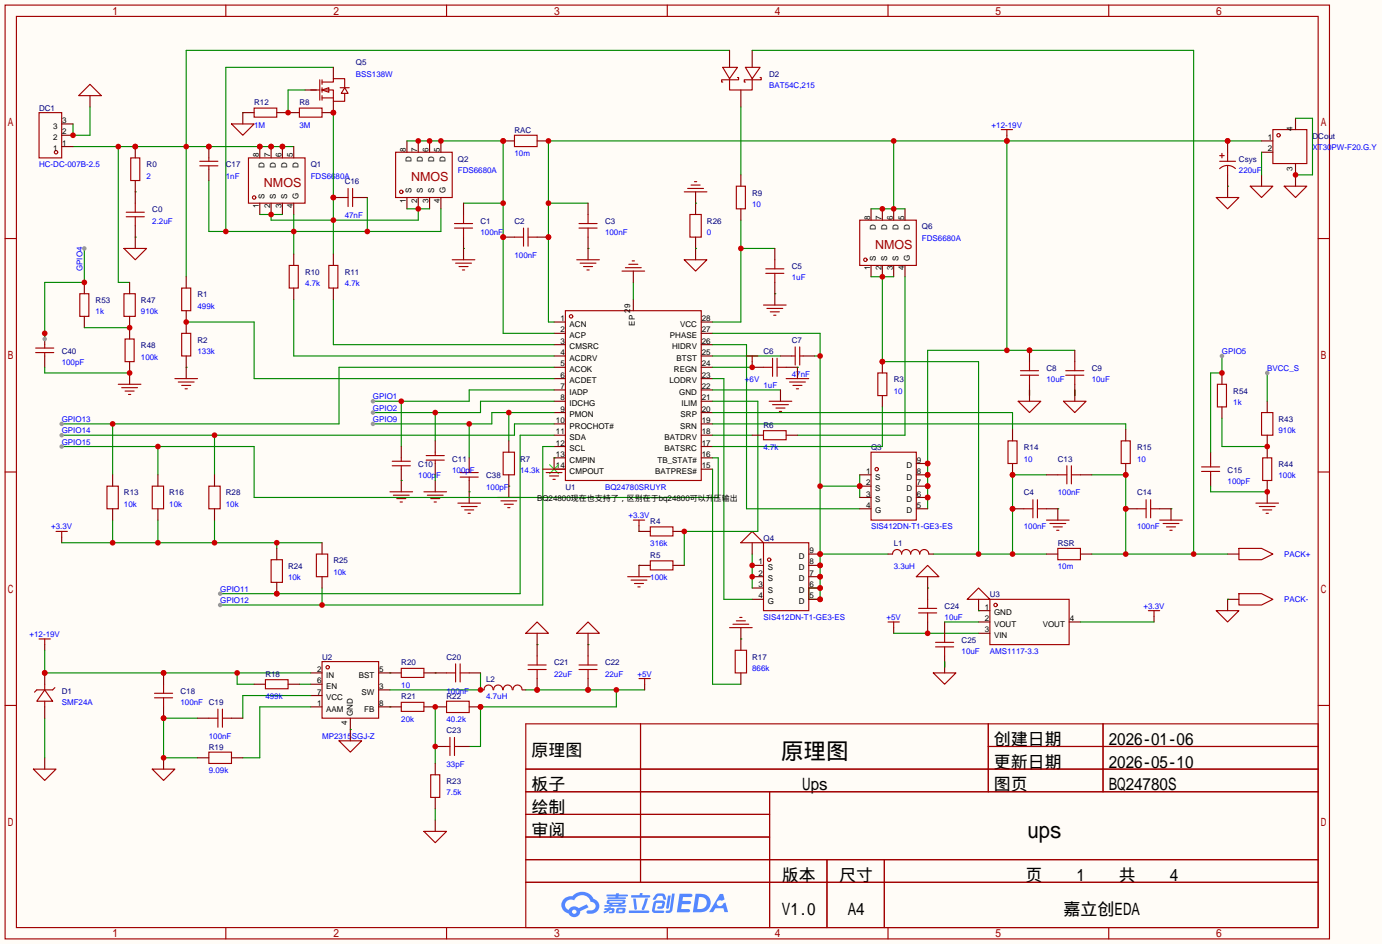
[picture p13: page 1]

原理图 | 原理图 | 创建日期 | 2026-01-06

更新日期 | 2026-05-10

板子 | Ups | 图页 | BQ24780S
绘制 | | ups
审阅

V1.0 | A4 | 嘉立创EDA

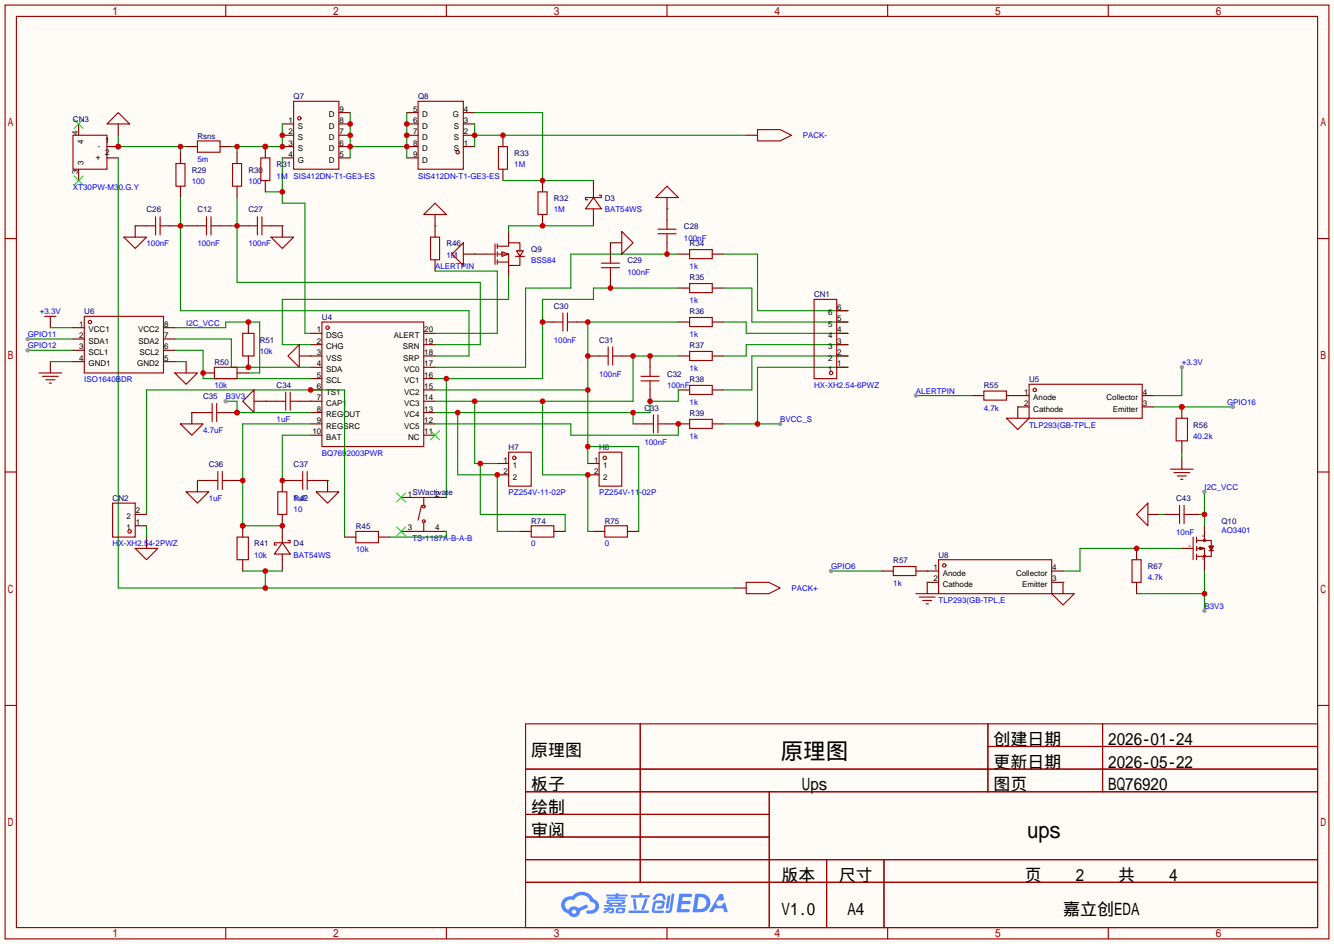
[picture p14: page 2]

原理图 | 原理图 | 创建日期 | 2026-01-24

更新日期 | 2026-05-22

板子 | Ups | 图页 | BQ76920
绘制 | | ups
审阅

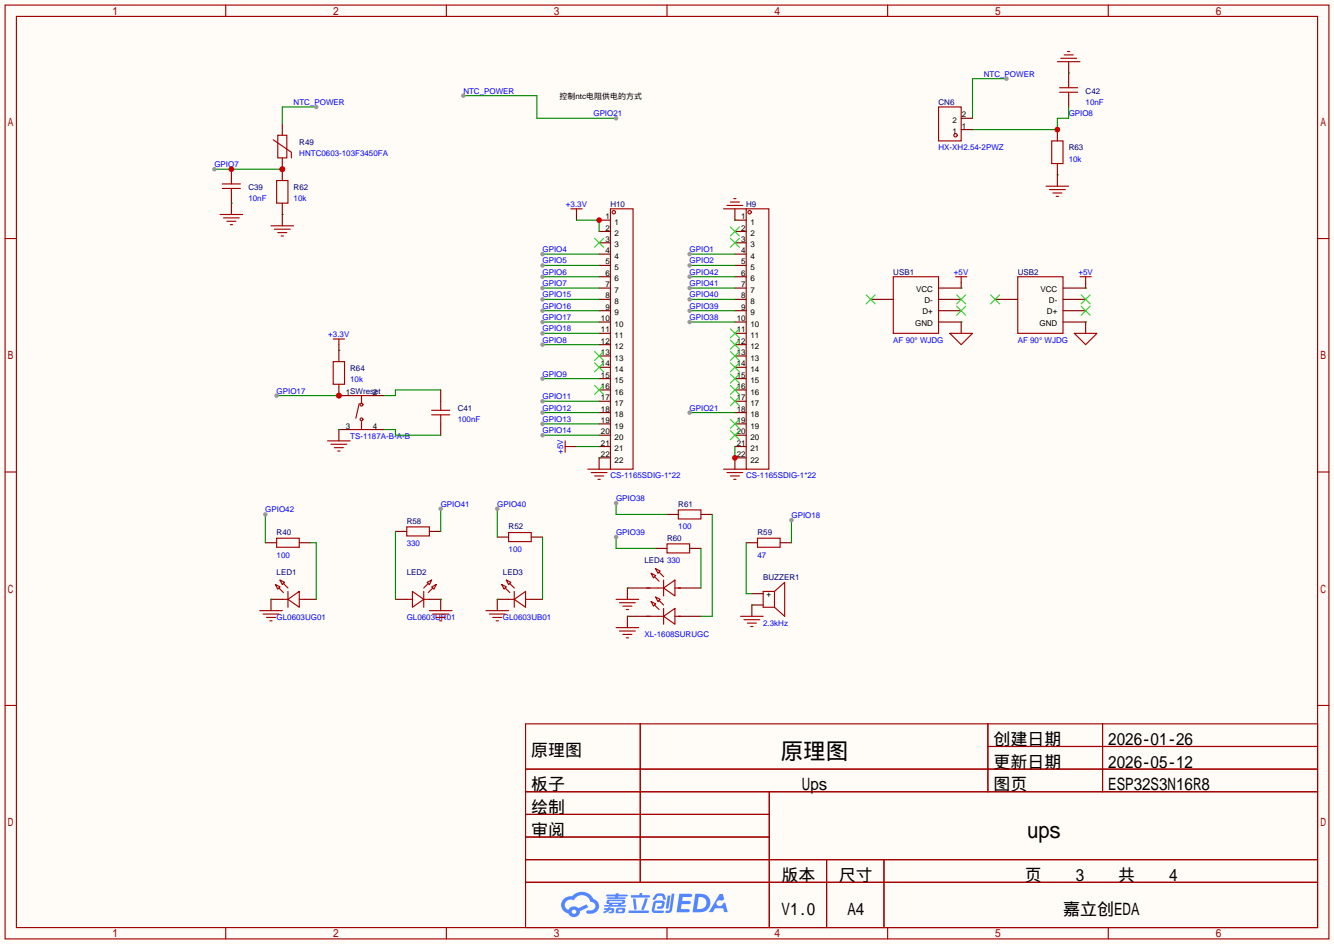
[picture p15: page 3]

原理图 | 原理图 | 创建日期 | 2026-01-26

更新日期 | 2026-05-12

板子 | Ups | 图页 | ESP32S3N16R8
绘制 | | ups
审阅

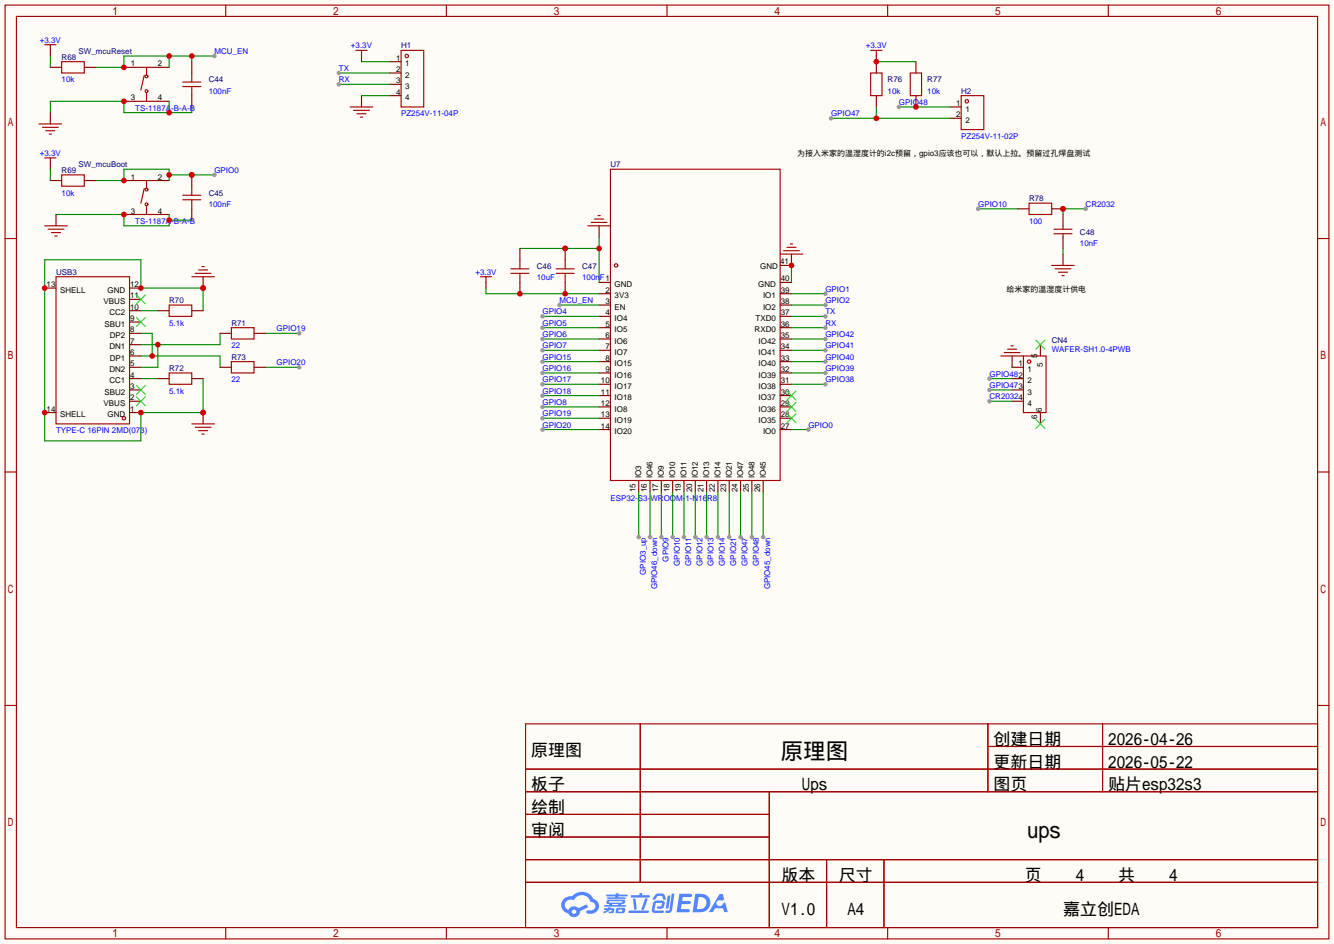
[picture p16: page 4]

原理图 | 原理图 | 创建日期 | 2026-04-26

更新日期 | 2026-05-22

板子 | Ups | 图页 | 贴片esp32s3
绘制 | | ups
审阅

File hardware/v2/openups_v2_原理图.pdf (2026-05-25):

## NMOS

## NMOS


原理图 | 原理图 | 创建日期 | 2026-01-06

更新日期 | 2026-05-10

板子 | Ups | 图页 | BQ24780S
绘制 | | ups
审阅

V1.0 | A4 | 嘉立创EDA


原理图 | 原理图 | 创建日期 | 2026-01-24

更新日期 | 2026-05-22

板子 | Ups | 图页 | BQ76920
绘制 | | ups
审阅


原理图 | 原理图 | 创建日期 | 2026-01-26

更新日期 | 2026-05-12

板子 | Ups | 图页 | ESP32S3N16R8
绘制 | | ups
审阅


原理图 | 原理图 | 创建日期 | 2026-04-26

更新日期 | 2026-05-22

板子 | Ups | 图页 | 贴片esp32s3
绘制 | | ups
审阅

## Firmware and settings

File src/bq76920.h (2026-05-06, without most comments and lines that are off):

#define BQ76920_H
#include <stdint.h>
#include "i2c_interface.h"
#define BQ76920_ADDRESS         0x08    ///< BQ76920 I2C地址
#define MAX_CELL_COUNT          5       ///< 最大电池单元数
#define DEFAULT_GAIN_MV_PER_LSB 0.380f  ///< 默认增益值 (mV/LSB)
#define DEFAULT_OFFSET_MV       0       ///< [修正] 默认偏移值 (mV)，原为99，现改为0以避免误差
#define RSENSE_VALUE           0.005f  // 检测电阻阻值5m
#define STATUS_REG_ADDR         0x00    ///< 状态寄存器
#define CELL_BALANCE_REG_ADDR   0x01    ///< 电池均衡寄存器
#define SYS_CTRL1_REG_ADDR      0x04    ///< 系统控制寄存器1
#define SYS_CTRL2_REG_ADDR      0x05    ///< 系统控制寄存器2
#define PROTECT1_REG_ADDR       0x06    ///< 短路保护寄存器1
#define PROTECT2_REG_ADDR       0x07    ///< 过流保护寄存器2
#define PROTECT3_REG_ADDR       0x08    ///< 压延保护延时
#define OV_TRIP_REG_ADDR        0x09    ///< 过压值寄存器
#define UV_TRIP_REG_ADDR        0x0A    ///< 欠压值寄存器
#define STAT_CC_READY       (1 << 7)
#define STAT_DEVICE_XREADY  (1 << 5)
#define STAT_OVRD_ALERT     (1 << 4) ///< 外部二级保护触发
#define STAT_UV             (1 << 3)
#define STAT_OV             (1 << 2)
#define STAT_SCD            (1 << 1)
#define STAT_OCD            (1 << 0)
#define ADC_ENABLE_BIT          0x10    ///< ADC使能位 SYS_CTRL1 bit4
#define TEMP_SELECT_BIT         0x08    ///< 温度选择位 SYS_CTRL1 bit3
#define CC_ENABLE_BIT           0x40    ///< 库仑计使能位 SYS_CTRL2 bit6
#define CHARGE_ENABLE_BIT       0x01    ///< 充电使能位 SYS_CTRL2 bit0
#define DISCHARGE_ENABLE_BIT    0x02    ///< 放电使能位 SYS_CTRL2 bit1
#define LOAD_PRESENT_BIT        0x04    ///< 负载检测位 SYS_CTRL1 bit2
#define VOLTAGE_BASE_ADDR       0x0C    ///< 电压寄存器基地址
#define VOLTAGE_REG_STEP        2       ///< 电压寄存器步长
#define VOLTAGE_HIGH_MASK       0x3F    ///< 电压高位掩码
#define VOLTAGE_ALL_ADDR        0x2A    ///< 所有电压寄存器地址高位 16bit
#define CURRENT_REG_HIGH        0x32    ///< 电流高字节寄存器
#define CURRENT_REG_LOW         0x33    ///< 电流低字节寄存器
#define CURRENT_ZERO_DRIFT      1     ///< 电流零漂值 (默认值，建议校准后覆盖)
#define CURRENT_SCALE_FACTOR    (8.44f / 5.0f)  ///< 电流缩放因子 //与检测电阻RSENSE_VALUE相关
#define TEMP_REG_HIGH           0x2C    ///< 温度高字节寄存器
#define TEMP_REG_LOW            0x2D    ///< 温度低字节寄存器
#define TEMP_HIGH_MASK          0x3F    ///< 温度高位掩码
#define CC_CFG_REG_ADDR         0x0B    ///< CC配置寄存器
#define GAIN_REG1_ADDR          0x50    ///< 增益寄存器1
#define GAIN_REG2_ADDR          0x59    ///< 增益寄存器2
#define OFFSET_REG_ADDR         0x51    ///< 偏移寄存器
#define BASE_GAIN_UV            365     ///< 基础增益值 (uV)
#define GAIN_MASK1              0x0C    ///< 增益掩码1
#define GAIN_MASK2              0xE0    ///< 增益掩码2
#define GAIN_SHIFT1             1       ///< 增益左移位数
#define GAIN_SHIFT2             5       ///< 增益右移位数
#define UV_TO_MV_FACTOR         1000.0f ///< uV转mV因子
#define TEMP_TABLE_START        -10     ///< 表格起始温度
#define TEMP_TABLE_END          95      ///< 表格结束温度
#define TEMP_TABLE_SIZE         106     ///< 表格元素个数
const uint16_t TEMP_LOOKUP_TABLE[] = {
    7373, 7310, 7246, 7179, 7110, 7040, 6967, 6893, 6816, 6738, // -10 ~ -1°C
    6658, 6577, 6493, 6408, 6322, 6234, 6145, 6054, 5962, 5870, // 0 ~ 9°C
    5776, 5681, 5586, 5489, 5393, 5295, 5198, 5100, 5002, 4903, // 10 ~ 19°C
    4805, 4707, 4610, 4512, 4416, 4319, 4224, 4129, 4035, 3942, // 20 ~ 29°C
    3849, 3758, 3668, 3579, 3491, 3405, 3320, 3236, 3154, 3073, // 30 ~ 39°C
    2993, 2915, 2838, 2763, 2690, 2618, 2548, 2479, 2411, 2345, // 40 ~ 49°C
    2281, 2218, 2157, 2098, 2039, 1983, 1927, 1873, 1821, 1770, // 50 ~ 59°C
    1720, 1672, 1625, 1579, 1534, 1491, 1449, 1408, 1369, 1330, // 60 ~ 69°C
    1293, 1256, 1221, 1187, 1154, 1121, 1090, 1060, 1030, 1001, // 70 ~ 79°C
    974, 947, 921, 895, 871, 847, 824, 801, 779, 758, // 80 ~ 89°C
    738, 718, 698, 680, 662, 644, // 90 ~ 95°C
};
#define INVALID_TEMPERATURE     -99.0f  ///< 无效温度值
#define INIT_RETRY_COUNT        5       ///< 初始化重试次数
#define INIT_DELAY_MS           10      ///< 初始化延时(ms)
#define ADC_STABILIZE_DELAY_MS  100    ///< ADC稳定延时(ms)
#define CALIBRATION_RETRY_DELAY_MS 100  ///< 校准重试延时(ms)
#define CALIBRATION_MIN_GAIN    0.30f   ///< 最小增益阈值
#define CALIBRATION_OFFSET_MIN  -50     ///< 偏移最小值
#define CALIBRATION_OFFSET_MAX  50      ///< 偏移最大值
#define CALIBRATION_GAIN_MIN    0.35f   ///< 增益最小值
#define CALIBRATION_GAIN_MAX    0.40f   ///< 增益最大值
#define DEFAULT_CALIBRATION_GAIN 0.381f ///< 默认校准增益
#define GAIN_ADJUSTMENT_FACTOR  1.0f ///< 增益调整因子
typedef enum {
    TEMP_SOURCE_INTERNAL = 0, // 内部 Die 温度
    TEMP_SOURCE_EXTERNAL = 1  // 外部热敏电阻 (TS1)
} BMS_TempSource_t;
typedef enum {
    OCD_DELAY_8_MS    = 0,
    OCD_DELAY_20_MS   = 1,
    OCD_DELAY_40_MS   = 2,
    OCD_DELAY_80_MS   = 3,
    OCD_DELAY_160_MS  = 4,
    OCD_DELAY_320_MS  = 5,
    OCD_DELAY_640_MS  = 6,
    OCD_DELAY_1280_MS = 7
} BMS_OCDDelay_t;
typedef enum {
    SCD_DELAY_70_US  = 0,
    SCD_DELAY_100_US = 1,
    SCD_DELAY_200_US = 2,
    SCD_DELAY_400_US = 3
} BMS_SCDDelay_t;
typedef enum {
    OV_DELAY_1_S  = 0,
    OV_DELAY_2_S  = 1,
    OV_DELAY_4_S  = 2,
    OV_DELAY_8_S  = 3
} BMS_OVDelay_t;
typedef enum {
    UV_DELAY_1_S  = 0,
    UV_DELAY_4_S  = 1,
    UV_DELAY_8_S  = 2,
    UV_DELAY_16_S = 3
} BMS_UVDelay_t;
static constexpr float BQ76920_OCD_THRESH_HIGH[] = {17, 22, 28, 33, 39, 44, 50, 56, 61, 67, 72, 78, 83, 89, 94, 100};
static constexpr float BQ76920_OCD_THRESH_LOW[]  = {8, 11, 14, 17, 19, 22, 25, 28, 31, 33, 36, 39, 42, 44, 47, 50};
static constexpr float BQ76920_SCD_THRESH_HIGH[] = {44, 67, 89, 111, 133, 155, 178, 200};
static constexpr float BQ76920_SCD_THRESH_LOW[]  = {22, 33, 44, 56, 67, 78, 89, 100};
static constexpr uint16_t BQ76920_OCD_DELAY_MS[] = {8, 20, 40, 80, 160, 320, 640, 1280};
static constexpr uint16_t BQ76920_SCD_DELAY_US[] = {70, 100, 200, 400};
struct BQ76920Data {
    uint16_t cell_voltage[MAX_CELL_COUNT];
    int16_t current;
    float temperature;
    float gain;
    int8_t offset;
    bool chg_enabled;
    bool dsg_enabled;
    unsigned long last_update;
    uint8_t actual_cell_count;
};
struct BQ76920_InitConfig {
    uint8_t cell_count;                   // 电池串数 (3-5)
    uint16_t cell_ov_threshold;           // 单节过压阈值 (mV)
    uint16_t cell_uv_threshold;           // 单节欠压阈值 (mV)
    BMS_OVDelay_t ov_delay;               // 过压延时
    BMS_UVDelay_t uv_delay;               // 欠压延时
    int16_t max_discharge_current;        // 最大放电电流 (mA)
    BMS_OCDDelay_t ocd_delay;             // 过流延时
    int16_t short_circuit_threshold;      // 短路阈值 (mA)
    BMS_SCDDelay_t scd_delay;             // 短路延时
    bool coulomb_counter_enabled;         // 是否启用库仑计
};
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

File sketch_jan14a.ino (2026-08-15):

/*
 * UPS Control System for ESP32 with BQ24780S and BQ76920
 */

#include <ESPAsyncWebServer.h>
#include <ArduinoJson.h>
#include <time.h>
#include <esp_task_wdt.h>

#include "src/debug.h"
#include "src/battery_chemistry.h"
#include "src/data_structures.h"
#include "src/pins_config.h"
#include "src/config_manager.h"
#include "src/hardware_interface.h"
#include "src/web_server.h"
#include "src/i2c_interface.h"
#include "src/bq24780s.h"
#include "src/bq76920.h"
#include "src/bms.h"
#include "src/battery_chemistry.h"
#include "src/power_management.h"
#include "src/system_management.h"
#include "src/WiFiManager.h"
#include "src/time_utils.h"
#include <SPIFFS.h>
#include "src/ups_hid_service.h"
#include "src/mqtt_service.h"
#include "src/XiaomiSensorBridge.h"
#include "src/shtc3.h"
#include "src/webhook_manager.h"

// =============================================================================
// OTA 固件特征标签
// 格式: "SIG:<PROJECT_NAME>:VER:<VERSION>"
// =============================================================================
char FIRMWARE_ID_TAG[50];

// =============================================================================
// Global Objects
// =============================================================================

ConfigManager configManager;
HardwareInterface* hardware = nullptr;
BMS* bms = nullptr;
PowerManagement* powerManagement = nullptr;
SystemManagement* systemManager = nullptr;
WebServer* webServer = nullptr;
WiFiManager* wifiManager = nullptr;

System_Global_State globalSystemState;
Configuration* systemConfig = nullptr;
BMS_Config_t* bmsConfig = nullptr;
Power_Config_t* powerConfig = nullptr;

bool g_force_factory_reset = false;
bool g_is_new_board = false;
UPS_HID_Service* upsHidService = nullptr;
MQTTService* mqttService = nullptr;
SHTC3* shtc3 = nullptr;
WebhookManager* webhookManager = nullptr;

// =============================================================================
// Helper Functions
// =============================================================================

bool checkFactoryReset() {
  pinMode(RESET_BUTTON_PIN, INPUT_PULLUP);
  char version[] = "SIG:OPENUPS-ESP32S3:VER:1.3.0";
  strcpy(FIRMWARE_ID_TAG, version);
  DBG.println(F("Checking for factory reset button..."));
  
  const unsigned long detectionTimeout = 3000;
  const unsigned long minPressDuration = 2500;
  unsigned long startTime = millis();
  unsigned long pressStartTime = 0;
  bool buttonPressed = false;
  
  while (millis() - startTime < detectionTimeout) {
    if (digitalRead(RESET_BUTTON_PIN) == LOW) {
      if (!buttonPressed) {
        pressStartTime = millis();
        buttonPressed = true;
        DBG.println(F("Reset button pressed, timing..."));
      }
      if (millis() - pressStartTime >= minPressDuration) {
        DBG.println(F("Factory Reset Triggered!"));
        return true;
      }
    } else if (buttonPressed) {
      DBG.println(F("Button released too early (< 2.5s)"));
      buttonPressed = false;
    }
    delay(1);
  }
  
  DBG.println(F("Normal Boot"));
  return false;
}

// 板型检测: GPIO47新板有外部上拉或下拉，旧板浮空
// 浮空: PULLUP读HIGH, PULLDOWN读LOW (跟随内部电阻)
// 有外部上下拉: 内部电阻被外部覆盖，两个读值不会同时满足浮空特征
bool detectBoardRevision() {
    pinMode(XIAOMI_SDA_PIN, INPUT_PULLUP);
    delay(2);
    bool valUp = digitalRead(XIAOMI_SDA_PIN);

    pinMode(XIAOMI_SDA_PIN, INPUT_PULLDOWN);
    delay(2);
    bool valDown = digitalRead(XIAOMI_SDA_PIN);

    pinMode(XIAOMI_SDA_PIN, INPUT);

    bool isFloating = valUp && !valDown;
    bool isNew = !isFloating;
    DBG.printf_P(PSTR("Board: PULLUP=%d PULLDOWN=%d -> %s board\n"),
                   valUp, valDown, isNew ? "NEW" : "OLD");
    return isNew;
}

template<typename T>
bool initModule(T*& module, const char* name) {
  unsigned long startTime = millis();
  DBG.printf_P(PSTR("%s::begin() started\n"), name);
  
  if (!module->begin()) {
    DBG.printf_P(PSTR("%s::begin() failed after %lu ms\n"), name, millis() - startTime);
    return false;
  }
  
  DBG.printf_P(PSTR("%s::begin() completed in %lu ms\n"), name, millis() - startTime);
  return true;
}

// =============================================================================
// System Initialization
// =============================================================================

bool initializeSystemModules() {
  DBG.println(F("=== Starting System Module Initialization ==="));
  
  // Step 1: ConfigManager
  DBG.println(F("Step 1: Initializing ConfigManager..."));
  configManager.begin();
  bool needsConfig = configManager.loadConfiguration(g_force_factory_reset);
  DBG.println(needsConfig ? F("ConfigManager: CONFIG MODE") : F("ConfigManager: NORMAL MODE"));
  delay(1);
  
  systemConfig = configManager.getSystemConfig();
  bmsConfig = configManager.getBMSConfig();
  powerConfig = configManager.getPowerConfig();
  
  if (!systemConfig || !bmsConfig || !powerConfig) {
    DBG.println(F("ERROR: Failed to get configuration pointers"));
    return false;
  }
  
  // Step 2: HardwareInterface
  DBG.println(F("Step 2: Initializing HardwareInterface..."));
  hardware = new HardwareInterface(*systemConfig, !g_is_new_board);
  if (!initModule(hardware, "HardwareInterface")) {
    delete hardware;
    hardware = nullptr;
    return false;
  }
  if (g_force_factory_reset) {
    hardware->setBuzzer(BUZZER_MODE_BEEP_ONCE);
  }
  
  delay(1);
  
  // Config mode: skip heavy modules
  if (needsConfig) {
    DBG.println(F("=== CONFIG MODE: Skipping BMS/Power/System modules ==="));
    bms = nullptr;
    powerManagement = nullptr;
    systemManager = nullptr;
    
    DBG.println(F("Step 6: Initializing WebServer (CONFIG MODE)..."));
    webServer = new WebServer(&configManager, nullptr, 80);
    
    DBG.println(F("Step 7: Initializing WiFiManager..."));
    wifiManager = new WiFiManager(hardware);
    delay(1);
    
    hardware->setLED(POWER_LED_PIN, LED_MODE_BLINK_SLOW);
    hardware->setRGBLED(RGB_MODE_BREATHING, {0, 0, 255});
    DBG.println(F("=== CONFIG MODE Initialization Complete ==="));
    return true;
  }
  
  // Normal mode: full initialization
  // Step 3: BMS
  DBG.println(F("Step 3: Initializing BMS..."));
  bms = BMS::create(static_cast<BatteryChemistry_t>(bmsConfig->chemistry),
                    hardware->getI2CInterface(), *bmsConfig);
  
  if (!initModule(bms, "BMS")) {
    DBG.println(F("WARNING: BMS not found, running in limited mode"));
    delete bms;
    bms = nullptr;
  }

  // Step 3.5: SHTC3 温湿度传感器（可选，共用 BMS 的 I2C 总线）
  DBG.println(F("Step 3.5: Initializing SHTC3..."));
  shtc3 = new SHTC3(hardware->getI2CInterface());
  if (!shtc3->begin()) {
    DBG.println(F("WARNING: SHTC3 not found, skipping"));
    delete shtc3;
    shtc3 = nullptr;
  }
  delay(1);

  // Step 4: PowerManagement
  DBG.println(F("Step 4: Initializing PowerManagement..."));
  DBG.printf_P(PSTR("PowerManagement: BMS pointer is %s\n"), bms ? "valid" : "nullptr");
  powerManagement = new PowerManagement(*powerConfig, *hardware);
  if (!initModule(powerManagement, "PowerManagement")) {
    DBG.println(F("WARNING: PowerManagement not found, running without charging control"));
    delete powerManagement;
    powerManagement = nullptr;
  }
  delay(1);
  
  // Step 5: UPS HID Service (conditional based on config)
  DBG.println(F("Step 5: Initializing UPS HID Service..."));
  if (systemConfig->hid_enabled) {
    upsHidService = new UPS_HID_Service();
    upsHidService->setDeviceIdentifier(systemConfig->identifier);
    upsHidService->setCapacityMode(systemConfig->hid_report_mode);
    upsHidService->setBatteryConfig(bmsConfig->cell_count,
        getChemistryLimits((BatteryChemistry_t)bmsConfig->chemistry).nominal_cell_mV,
        bmsConfig->nominal_capacity_mAh);
    //暂不启动，等待系统启动稳定后启动
  } else {
    DBG.println(F("UPS HID Service disabled in configuration"));
    upsHidService = nullptr;
  }
  delay(1);

  // Step 5.5: Xiaomi Sensor Bridge (仅新板, 条件创建, 延迟启动)
  XiaomiSensorBridge* xiaomiBridge = nullptr;
  if (g_is_new_board && systemConfig->xiaomi_sensor_enabled) {
      DBG.println(F("Step 5.5: Xiaomi Sensor Bridge (will start delayed)..."));
      xiaomiBridge = new XiaomiSensorBridge();
      xiaomiBridge->setConfig(systemConfig);
  } else {
      if (!g_is_new_board) {
          DBG.println(F("Xiaomi Sensor Bridge: skipped (old board)"));
      } else {
          DBG.println(F("Xiaomi Sensor Bridge: disabled in config"));
      }
  }
  delay(1);

  // Step 6: SystemManagement
  DBG.println(F("Step 6: Initializing SystemManagement..."));
  // MQTT Service initialization (conditional based on config)
  if (systemConfig->mqtt_broker[0] != 0 && systemConfig->mqtt_port > 0) {
    mqttService = new MQTTService();
  }

  // SystemManagement with optional MQTT service
  systemManager = new SystemManagement(*hardware, bms, powerManagement, configManager, upsHidService, mqttService, xiaomiBridge, shtc3);
  if (!systemManager->initialize()) {
    DBG.println(F("ERROR: Failed to initialize SystemManagement"));
    delete systemManager;
    systemManager = nullptr;
    delete shtc3;
    shtc3 = nullptr;
    return false;
  }
  DBG.println(F("SystemManagement initialized successfully"));
  delay(1);

  // Step 6.5: WebhookManager 延迟启动
  // 与 HID / MQTT / XiaomiBridge 一致，在 SystemManagement::onDelayedStart() 中启动
  delay(1);

  // Step 7: WebServer
  DBG.println(F("Step 7: Initializing WebServer..."));
  webServer = new WebServer(&configManager, systemManager, 80);
  delay(1);
  
  // Step 8: WiFiManager
  DBG.println(F("Step 8: Initializing WiFiManager..."));
  wifiManager = new WiFiManager(hardware);
  delay(1);
  
  DBG.println(F("=== All System Modules Initialized Successfully ==="));
  return true;
}

// =============================================================================
// Arduino Setup
// =============================================================================

void setup() {
  DBG.begin(115200);

  // 初始化 SPIFFS 文件系统
  if (!SPIFFS.begin(true)) {
    DBG.println(F("SPIFFS: Mount failed, formatting..."));
  } else {
    DBG.println(F("SPIFFS: Mounted OK"));
  }

  // 初始化日志系统（DEBUG_MODE=1时生效）
  #if DEBUG_MODE
  DebugLogger::getInstance().begin(SPIFFS, DEFAULT_LOG_MODE);
  DBG.println(F("DebugLogger: Initialized"));
  #endif

  g_force_factory_reset = checkFactoryReset();
  g_is_new_board = detectBoardRevision();

  DBG.println(F("=== UPS Control System Starting ==="));
  DBG.printf_P(PSTR("Build: %s %s\n"), __DATE__, __TIME__);

  if (!initializeSystemModules()) {
    DBG.println(F("FATAL Error: System initialization failed"));
    DBG.println(F("System will restart automatically..."));
    delay(100);
    while (1) delay(1000);
  }
  
  // WiFi setup - 统一使用begin()处理所有情况
  DBG.println(F("Initializing WiFi Manager..."));
  wifiManager->begin(systemConfig);
  
  DBG.println(F("Starting WebServer..."));
  webServer->begin();
  
  initTimeSystem(28800, systemConfig->ntp_server); 
  
  DBG.println(F("=== System Setup Complete ==="));
}

// =============================================================================
// Arduino Loop
// =============================================================================

void loop() {
  if (wifiManager) wifiManager->loop();
  updateTimeSystem();
  
  // Config mode: only basic services, reduced frequency to save power
  if (!systemManager) {
    hardware->update();
    delay(500);  // 降低循环频率，减少芯片发热
    return;
  }
  
  if (!systemManager->isSystemReady()) {
    delay(100);
    return;
  }
  
  systemManager->update();
  
  // WebSocket 数据推送已移至客户端 "get" 消息驱动（onWsEvent 中处理），
  // 避免从主循环跨任务调用 ws.textAll() 导致数据竞争
  
  // 定期清理断开的 WebSocket 客户端，防止 20+ 天运行后内存泄漏
  static unsigned long lastWsCleanup = 0;
  if (millis() - lastWsCleanup > 60000) {
    webServer->cleanupWsClients();
    lastWsCleanup = millis();
  }

  delay(10);
}

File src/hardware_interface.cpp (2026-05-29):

#include "hardware_interface.h"
#include "utils.h"
#include <Arduino.h>
#include <FastLED.h>
#include <math.h>
#include "debug.h"

static HardwareInterface* g_hardware_instance = nullptr;

HardwareInterface::HardwareInterface(uint8_t led_brightness, uint8_t buzzer_volume, bool buzzer_enabled, bool init_rgb)
    : init_rgb_(init_rgb), i2cInterface_(), system_status_(0), last_update_time_(0), last_led_update_time_(0),
      button_press_start_time_(0), flag_acok_changed_(false), flag_prochot_alert_(false),
      flag_tbstat_changed_(false), flag_bms_alert_(false), flag_button_pressed_(false),
      button_state_(BTN_IDLE), last_acok_state_(false), last_prochot_state_(false),
      last_tbstat_state_(false), rgb_mode_(RGB_MODE_OFF), rgb_color_{0, 0, 0},
      buzzer_mode_(BUZZER_MODE_OFF),
      buzzer_last_time_(0),
      buzzer_beep_on_(false),
      buzzer_state_(false) {
    
    led_brightness_ = Utils::applyGammaMapping(min(led_brightness, (uint8_t)100), 80);
    buzzer_volume_ = Utils::applyGammaMapping(min(buzzer_volume, (uint8_t)100), 150);
    buzzer_enabled_ = buzzer_enabled;
    
    memset(led_modes_, LED_MODE_OFF, sizeof(led_modes_));
    
    // Initialize ADC calibration coefficients to default (100 = 1.00x)
    memset(adc_calibration_, ADC_CAL_DEFAULT_VALUE, sizeof(adc_calibration_));
    
    // Initialize Preferences for ADC calibration storage
    adc_cal_preferences_.begin(ADC_CAL_NVS_NAMESPACE, false);
    
    g_hardware_instance = this;
    
    DBG.printf_P(PSTR("HW: brightness=%u%%->%u, volume=%u%%->%u, enabled=%s\n"),
                   min(led_brightness, (uint8_t)100), led_brightness_,
                   min(buzzer_volume, (uint8_t)100), buzzer_volume_,
                   buzzer_enabled_ ? "yes" : "no");
}

HardwareInterface::HardwareInterface(const Configuration& config, bool init_rgb)
    : HardwareInterface(config.led_brightness, config.buzzer_volume, config.buzzer_enabled, init_rgb) {}

bool HardwareInterface::begin() {
    DBG.println(F("HW: Initializing..."));
    
    initGPIOs();

    if (!i2cInterface_.initialize(I2C_SDA_PIN, I2C_SCL_PIN, 100000)) {
        DBG.println(F("HW: I2C init failed"));
        return false;
    }

    //i2cInterface_.scanI2CBus();
    
    attachInterrupt(digitalPinToInterrupt(BQ24780S_ACOK_PIN), handleAcokInterrupt, CHANGE);
    attachInterrupt(digitalPinToInterrupt(BQ24780S_PROCHOT_PIN), handleProchotInterrupt, CHANGE);
    attachInterrupt(digitalPinToInterrupt(BQ24780S_TBSTAT_PIN), handleTbstatInterrupt, CHANGE);
    attachInterrupt(digitalPinToInterrupt(BQ76920_ALERT_PIN), handleBmsAlertInterrupt, RISING); 
    attachInterrupt(digitalPinToInterrupt(RESET_BUTTON_PIN), handleButtonInterrupt, FALLING);
    
    // Initialize ADC calibration from Preferences
    initADCCalibration();
    
    DBG.println(F("HW: Init complete"));
    return true;
}

void HardwareInterface::initADCCalibration() {
    DBG.println(F("HW: Loading ADC calibration from Preferences..."));
    bool any_loaded = false;
    
    for (uint8_t i = 0; i < ADC_CAL_PIN_COUNT; i++) {
        char key[16];
        snprintf(key, sizeof(key), "pin_%u", ADC_CAL_PINS[i]);
        
        uint32_t cal_value = adc_cal_preferences_.getUInt(key, ADC_CAL_DEFAULT_VALUE);
        if (cal_value >= ADC_CAL_MIN_VALUE && cal_value <= ADC_CAL_MAX_VALUE) {
            adc_calibration_[i] = (uint8_t)cal_value;
            any_loaded = true;
            DBG.printf_P(PSTR("HW: ADC cal pin %u -> %u (%.2fx)\n"),
                           ADC_CAL_PINS[i], adc_calibration_[i], adc_calibration_[i] / 100.0f);
        }
    }
    
    if (any_loaded) {
        DBG.println(F("HW: ADC calibration loaded from Preferences"));
    } else {
        DBG.println(F("HW: No valid ADC calibration found, using defaults"));
    }
}

void HardwareInterface::initGPIOs() {
    // Input pins
    pinMode(BQ24780S_ACOK_PIN, INPUT);      
    pinMode(BQ24780S_PROCHOT_PIN, INPUT);   
    pinMode(BQ24780S_TBSTAT_PIN, INPUT); 
    pinMode(BQ76920_ALERT_PIN, INPUT); 
    
    // Output pins (RGB_LED_PIN 由 init_rgb_ 条件控制)
    const uint8_t output_pins[] = {
        BQ76920_I2CVCC_PIN, POWER_LED_PIN, CHARGING_LED_PIN, DISCHARGING_LED_PIN,
        WIFI_FAIL_LED_PIN, WIFI_SUCCESS_LED_PIN, BUZZER_PIN,
        TEMP_POWER_PIN
    };

    for (uint8_t pin : output_pins) {
        pinMode(pin, OUTPUT);
        digitalWrite(pin, LOW);
    }

    if (init_rgb_) {
        pinMode(RGB_LED_PIN, OUTPUT);
        digitalWrite(RGB_LED_PIN, LOW);
        FastLED.addLeds<WS2812, RGB_LED_PIN, GRB>(leds_, 1);
        FastLED.setBrightness(led_brightness_);
    } else {
        DBG.println(F("HW: RGB LED skipped (slave I2C mode)"));
    } 
    
    analogSetAttenuation(ADC_11db); 
    analogReadResolution(12);
    
    DBG.println(F("HW: GPIOs configured"));
}
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

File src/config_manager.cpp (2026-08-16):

#include "config_manager.h"
#include "Arduino.h"
#include "pins_config.h"
#include "event_bus.h"
#include "event_types.h"
#include "debug.h"
#include "i18n.h"
#include "webhook_presets.h"
#include <SPIFFS.h>
#include <ArduinoJson.h>

// SPIFFS 互斥锁（定义于 system_management.cpp，保护 /log /raw 等并发文件访问）
extern SemaphoreHandle_t g_spiffs_mutex;

// Webhook 配置在 SPIFFS 中的存储路径（NVS 20KB 无法容纳 3849 字节的结构体）
#define WEBHOOK_CONFIG_PATH "/webhook_cfg.json"

// 静态实例指针，供事件回调使用
static ConfigManager* s_configManagerInstance = nullptr;

// 仅用于 NVS 迁移的 v1 冻结布局（对应加 config_version/chemistry 之前的 BMS_Config_t）
// 注意：sizeof(BMS_Config_v1_t) == sizeof(BMS_Config_t)（对齐填充抵消了新增字段），
// 因此 v2 使用新 key "bms_cfg2" 区分，绝不能只靠长度判断版本。
typedef struct {
    uint8_t cell_count;
    uint32_t nominal_capacity_mAh;
    uint16_t cell_ov_threshold;
    uint16_t cell_uv_threshold;
    uint16_t cell_ov_recover;
    uint16_t cell_uv_recover;
    uint16_t max_charge_current;
    uint16_t max_discharge_current;
    uint16_t short_circuit_threshold;
    float temp_overheat_threshold;
    bool balancing_enabled;
    float balancing_voltage_diff;
} BMS_Config_v1_t;

ConfigManager::ConfigManager() : m_isConfigModeRequired(false) {
    web_username_[0] = '\0';
    web_password_[0] = '\0';
    loadDefaults();
}

void ConfigManager::begin() {
    s_configManagerInstance = this;
    EventBus::getInstance().subscribe(EVT_CONFIG_SYSTEM_CHANGE_REQUEST, onConfigChangeRequest);
}

bool ConfigManager::loadConfiguration(bool forceReset) {
    DBG.println(F("Loading configuration from flash..."));

    // 加载 Web 访问凭证（独立 NVS key，与主配置结构体解耦，
    // 旧固件升级后主配置有效但凭证为空 → Web 层强制先设置账户）
    if (!forceReset) {
        preferences.begin("ups_config", true);
        size_t ulen = preferences.getBytes("web_user", web_username_, sizeof(web_username_) - 1);
        size_t plen = preferences.getBytes("web_pass", web_password_, sizeof(web_password_) - 1);
        preferences.end();
        web_username_[ulen] = '\0';
        web_password_[plen] = '\0';
    }

    // 1. 优先判断：如果强制重置，直接恢复默认值并进入配置模式
    // （硬件按键强制重置同时清除访问凭证 —— 忘记密码时的唯一恢复路径，
    //  重置后进入配置模式，向导会强制设置新账户）
    if (forceReset) {
        DBG.println(F("Force reset requested - resetting to defaults"));
        clearWebCredentials();
        resetToDefaults();
        m_isConfigModeRequired = true;

        // 保存默认配置到 Flash
        writeToFlash();
        return true;
    }
    
    // 2. 尝试从 NVS 读取配置
    preferences.begin("ups_config", true); // ReadOnly mode
    
    // Load all configurations together
    Configuration loadedSystemConfig;
    BMS_Config_t loadedBMSConfig;
    Power_Config_t loadedPowerConfig;
    
    size_t systemBytes = preferences.getBytes("sys_config", &loadedSystemConfig, sizeof(Configuration));
    size_t bmsBytes = preferences.getBytes("bms_cfg2", &loadedBMSConfig, sizeof(BMS_Config_t));
    bool bmsMigrated = false;
    if (bmsBytes != sizeof(BMS_Config_t) ||
        loadedBMSConfig.config_version != BMS_CONFIG_VERSION) {
        // 尝试旧结构迁移（升级用户绝不能被打回配置模式）
        BMS_Config_v1_t v1;
        size_t v1Bytes = preferences.getBytes("bms_config", &v1, sizeof(BMS_Config_v1_t));
        if (v1Bytes == sizeof(BMS_Config_v1_t) && v1.cell_count >= 3 && v1.cell_count <= 5) {
            memset(&loadedBMSConfig, 0, sizeof(BMS_Config_t));
            loadedBMSConfig.config_version        = BMS_CONFIG_VERSION;
            loadedBMSConfig.chemistry             = CHEM_NCM;   // 旧配置一律 NCM，绝不猜化学
            loadedBMSConfig.cell_count            = v1.cell_count;
            loadedBMSConfig.nominal_capacity_mAh  = v1.nominal_capacity_mAh;
            loadedBMSConfig.cell_ov_threshold     = v1.cell_ov_threshold;
            loadedBMSConfig.cell_uv_threshold     = v1.cell_uv_threshold;
            loadedBMSConfig.cell_ov_recover       = v1.cell_ov_recover;
            loadedBMSConfig.cell_uv_recover       = v1.cell_uv_recover;
            loadedBMSConfig.max_charge_current    = v1.max_charge_current;
            loadedBMSConfig.max_discharge_current = v1.max_discharge_current;
            loadedBMSConfig.short_circuit_threshold = v1.short_circuit_threshold;
            loadedBMSConfig.temp_overheat_threshold = v1.temp_overheat_threshold;
            loadedBMSConfig.balancing_enabled     = v1.balancing_enabled;
            loadedBMSConfig.balancing_voltage_diff = v1.balancing_voltage_diff;
            bmsBytes = sizeof(BMS_Config_t);   // 让后续有效性判断通过
            bmsMigrated = true;
            DBG.println(F("BMS config migrated v1 -> v2 (chemistry=NCM)"));
        }
    }
    size_t powerBytes = preferences.getBytes("power_config", &loadedPowerConfig, sizeof(Power_Config_t));

    preferences.end();

    // 迁移成功立即回写新 key，下次启动直接走 v2 路径
    if (bmsMigrated) {
        preferences.begin("ups_config", false);
        preferences.putBytes("bms_cfg2", &loadedBMSConfig, sizeof(BMS_Config_t));
        preferences.end();
    }
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

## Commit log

2026-05-06 修复：蜂鸣器响声问题；bq76920库设置短路与过流电流的计算逻辑问题；前端配置模式，footer等不正确显示； 新增：bms持久化累积变量，充电阶段soh学习，增加ota重启前的数据保存，降低soc delta阈值，循环技术累计法，前端tip信息提示等。 更改版本号为1.1.0
    [bms.cpp, bms.h, bq76920.cpp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]
2026-05-06 修改了充电判断停止的一些逻辑； 修复了前端页面显示的一些bug。
2026-05-06 修正bq76920文档中进入shipmode的错误描述； 修正bq76920库进入shipmode的错误指令； 修正获取温度与电压的边界检测。
2026-05-07 优化充电的逻辑
2026-05-08 修复由于acok的抖动造成充电停止的问题。 更新版本号为1.1.1
2026-05-11 新增对bq24800的支持 新增对米家温湿度计的模拟 新增bms数据重置 新增tip清除 修改bms的一些策略
2026-05-12 新增设备重启按钮 新增tip清除功能 修改bms的soh计算逻辑beta
2026-05-13 新增一些参考资料
2026-05-13 新增v2版本的硬件
    [BOM_4层非开发板版本_openups.xlsx]
2026-05-13 增加致谢
2026-05-16 新增串口输出开关文件debug.cpp，用于关闭串口输出，节约运算资源 调整bms的一些策略 完成米家温湿度计的接入
2026-05-16 更新原理图与pcb
    [BOM_4层非开发板版本_openups.xlsx]
2026-05-20 PCB进行了一些优化，修正了4层板一处可能影响充电电流采集的错误连线。 bms进行了一些bug的修改 bms进行了一些节能逻辑的优化 完成对米家温湿度计的支持（开发板的esp32s3因为占用了gpio48，所以暂不支持） 优化了一些其他细节
    [BOM_4层非开发板版本_openups.xlsx]
2026-05-20 更新一些说明
2026-05-24 一些细节逻辑修改
2026-05-25 更新了外壳，线路板等。
    [BOM_4层非开发板版本_openups.xlsx, ups外壳.skp, ups外壳.stl]
2026-05-25 更新描述
2026-05-25 更新版本号到1.1.5
2026-05-29 合并了三个分支的优化 支持shtc3传感器（若有） 优化了各种细节 版本号更新到1.1.6
2026-05-29 修复缩小栈空间带来可能崩溃重启的问题
2026-06-01 电池组电压默认改为每节电池之和
2026-06-08 修复shtc3的初始化休眠问题
2026-06-08 优化bms的自耗电逻辑
2026-06-11 新增实验性功能：自消耗电流与电池内阻粗分析
2026-06-12 完善均衡的提示逻辑
2026-06-12 对电池内阻测试功能进行重构
2026-06-14 修复自消耗计算的一些bug
2026-06-16 修复一处文件过多可能引起看门狗超时崩溃的bug 增加查看bms保存的原始文件
2026-06-22 更新readme 增加自动翻译的英文
2026-06-24 修正mqtt在连接异常断线后的重连问题。
2026-06-26 增加多语言的支持
2026-06-26 增加电芯内阻的MQTT HA自动发现配置
2026-06-28 新增了调试信息输出为文件，但调试模式默认是关闭的，需要到debug.h去打开 修正了自消耗与内阻计算定时24小时的时间内部溢出bug
2026-07-07 新增了web界面需要账号密码登录，以及其他一些逻辑细节完善修改。
2026-07-08 细微的调整
2026-07-14 增加对磷酸铁锂的支持，但并没有对磷酸铁锂进行测试。
2026-07-14 更新介绍
2026-07-17 修复一些显示bug 完善ocv-soc表中的40-80%段
2026-08-15 1.新增webhook初始版 2.修改可能存在的内存泄露问题
2026-08-15 更新readme
2026-08-16 webhook新增预置告警模板库与NE运算符，支持科学阈值一键应用
2026-08-17 添加遗忘的文件。tortoiseGit升级后，commit ui没有提示新文件，造成遗漏，sorry.
